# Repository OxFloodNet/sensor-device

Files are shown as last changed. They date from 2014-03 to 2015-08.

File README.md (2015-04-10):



#OxFloodNet Sensor Device

Sensor code (originally started at Sushack 2013 - http://www.sushack.co.uk/)
## Requirements
Base components:
 * Ciseco RFu-328 (SRF radio + ATMega328 module) with an ultrasonic sensor
 * Schematic and parts list shown in [PCB directory](https://github.com/OxFloodNet/sensor-device/tree/master/PCB)

## Output 
 * LLAP to transmit sensor readings
 * Sends messages in format: a<device ID><sensor ID><value><dash padding til 12 chars>
 * Example message: aR1U65------
 * Meaning: Device R1, Ultrasonic Sensor, Reading: 65cm to water surface.
 * Example message: aR1B5500----
 * Meaning: Device R1, Battery sensor, Reading: 5500mV (5.5v remaining in battery)
 
Typical sensor deployment
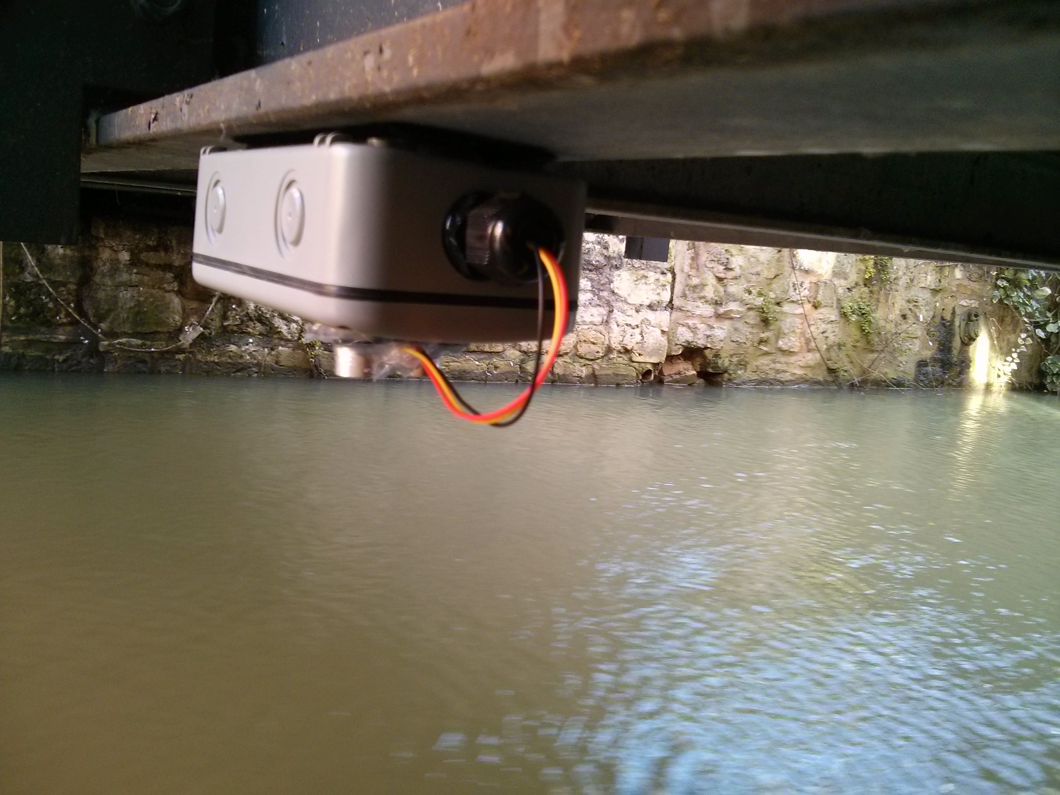
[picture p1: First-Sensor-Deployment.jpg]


Testing

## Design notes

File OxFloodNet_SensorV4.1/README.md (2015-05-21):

Oxford Flood Network Sensor Code
=================================

Version 4.1.0 - Codename: 

Features: 
* Compatible with Maxbotix ultrasonic sensor range using PWM interface
* Dallas DS18B20 Temperature sensor for speed of sound compensation and Unique ID
* Unique 8 hex character Node number
* Variable wake timer with jumpers
* Uses an Extended LLAP message format
* Variable polling during startup phase to test device is working
* STARTvvv message sent 5 times at start, vvv indicates firmware version
* Battery message sent every 10 readings
* Reset reedswitch.
* Test mode for verifying the hardware works correctly and for remote firmware loads.

Issues: 
* None identified yet

The Oxford Flood Network sensor V4.0 is based on the Arduino core and is written for the Ciseco RFu328 which uses the ATMega328 microcontroller. The code uses some direct register acesses, so may not be directly compatible with other non-ATMega328 based boards without modification. It uses the Ciseco/Wireless Things RFu328 which includes the Ciseco/Wireless Things SRF radio transceiver module. This is used to manage the very low-power sleep mode, with the SRF waking the 328 using an interrupt pin after the wakeup time is reached.

The code is intended to be generic, with the sleep interval set by jumpers on the PCB. These are directly connected to ATMega328 pins which are read at setup() and converted into parameters for "Wakeup Period". The board has no FTDI connector pins which means that the RFu328 must either be programmed using the Ciseco RFu dev board, Voyager adaptor or programmed over the air while in test mode.

Jumpers
-------

The 2 jumpers labeled 1 and 2 represent *Wakeup Period* and has four possible options:

<pre>
 1   2    Sleep Interval
[ ] [ ] - 15 Minutes (default)
[X] [X] - 10 Minutes
[ ] [X] - 5 Minutes
[X] [ ] - 1 Minute
</pre>

The Test jumper should only be used for testing the sensor. This will allow two way communication between a laptop and sensor to perform validation on the harware. Please see the Test Mode description below for full details.

ATMega328 I/O Pin usage
-----------------------

|I/O|Use|
|---|---|
|D0|Tx SRF Radio Module|
|D1|Rx SRF Radio Module|
|D2|Wakeup interrupt|
|D3|Ultrasonic Sensor input|
|D4|SRF Sleep selection|
|D5|Temperature sensor, One Wire bus|
|D6|Ultrasonic Sensor Enable - Low to enable|
|D7|Not used|
|D8|SRF Radio enable - High to enable|
|D9|Wakeup period|
|D10|Wakeup period|
|D11|Not Used|
|D12|Not Used|
|D13|Test Mode jumper. Low selects test mode on reset|
|A0-A5|Not used|

When programming sketches using the Arduino IDE, select board type "Arduino Uno".

Test Mode
=========

The test mode is available over the wireless connection so this must be working. The RFu-328 must also have the V4 sketch loaded. A Ciseco SRFStick is required to communicate with the sensor and needs to be configured to communicate with the sensor on an alternative PANID (Network ID). An alternative PANID is used so that communcations with the sensor under test do not interfere with other working sensors and similar equipment that is located nearby.

Setting up the SRFStick
-----------------------

You need to communicate with the SRFStick using suitable Serial terminal emulation software, for example TeraTerm on Windows. To setup the correc parameters you need to enter a number of AT commands. Enter AT mode by typing `+++`, you should then receive the OK response, if not repeat again. Once you see the OK response, enter the following AT commands, ensure each gives an OK response. They set the PANID to 2305, set the packet size to maximum, make the configuration active and exit AT mode.

<pre>
+++
OK
ATID2305
OK
ATPKF0
OK
ATAC
OK
ATDN
OK
</pre>

Once setup, placing a jumperlink on the `Test` pins and resetting the sensor by sliding a magnet along the edge near the battery should result in the menu being shown.

<pre>
Oxford Flood Network Sensor
===========================

Test Menu
=========
0 - Display Menu
1 - Display Address
2 - Read Temperature
3 - Read Raw Distance
4 - Read Distance
5 - Battery Voltage
6 - Read Polling Rate
Choice: [0 - 6]
</pre>

To select an option press the number 0-6. Options 1, 5 and 6 return immediately, options 2, 3 and 4 repeatedly update the results until a key is pressed. The interval between readings is 1/2 second. This allows changes in temperature and distance to be seen. Option 0 re-displays the menu.

### Sensor Address
This displays part of the unique ID from the temperature sensor. The family ID, CRC and extra 0's are removed to give an 8 hex character node address. A value of 00000000 indicates the address was not read from the sensor and needs ot be checked.

<pre>
Address: 04BB8405
</pre>

### Read Temperature
Displays the current temperature reading. Touching the sensor should increase the reading so show that it is working. A value of 85.00C indicates that the sensor is not functioning and may need to be checked or replaced.
<pre>
Read Temperature
Temperature: 17.50C
</pre>

### Read Raw Distance
Displays the raw distance or *Error* if the sensor is outside of its usable range.
<pre>
Read Raw Distance
Raw Distance: 160cm
</pre>

### Read Distance
Displays the temperature, raw distance and compensated distance or *Error* if the sensor is outside of its usable range.
<pre>
Read Distance
Temperature: 17.50C  Raw Distance: 160cm  Distance: 159cm
</pre>

### Battery Voltage
Display the battery voltage reading.
<pre>
Read Battery Voltage
Battery: 3.3943V
</pre>

### Read Polling rate
Displays the state of the two polling/sleep interval jumpers and the rate it represents.
<pre>
Read Polling Rate
Pin 1 No Jumper
Pin 2 No Jumper
Polling: 0
15 Minutes
</pre>

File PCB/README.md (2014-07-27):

This repository contains the EAGLE files and gerbers for creating an Oxfloodnet Sensor PCB v3.1. 

The sensor device has the following features:
* Arduino-compatible code wireless sensor node
* Wireless
  * Transmits using 433, 868 or 915* MHz  (*USA only)
  * LLAP Protocol
  * Up to 200m range
  * Chip, Wire Whip and External (u.FL) antenna options
* Power: 
  * Option for Long-life (1 x 3.6v Tadiran Lithium Cell) or Off-the Shelf (2 x 1.6v AA Batteries)
  * Battery voltage reading sent every 10th cycle
  * Extremely low power sleep mode (~30uA)
* Maxbotix ultrasonic ranger
  * Compatible with most Maxbotix sensors
  * Maxbotix MB7060 XL-MaxSonar-WR1 IP67 outdoor-rated sensor recommended due to humidity/condensation issues
  * Maxbotix MB1230 works but has condensation issues above streams
* DS18B20 temperature sensor 
  * to compensate for speed of sound in different conditions
  * Temperature data also a useful byproduct
  * Molex header connection to board for easy maintenance
* Jumpers/Headers
  * Control poll cycle (10s, 5, 10 or 15 minutes depending on jumpers)
  * FTDI connector for programming sketch to RFu-328 (not powered)
  * Molex temperature connector
  * Maxbotix 7-way header
  
See Arduino [device code](https://github.com/OxFloodNet/sensor-device/tree/master/OxFloodNet_Sensor) for more specific info about controlling these.

A schematic of the Oxfloodnet Sensor PCB v3.1  
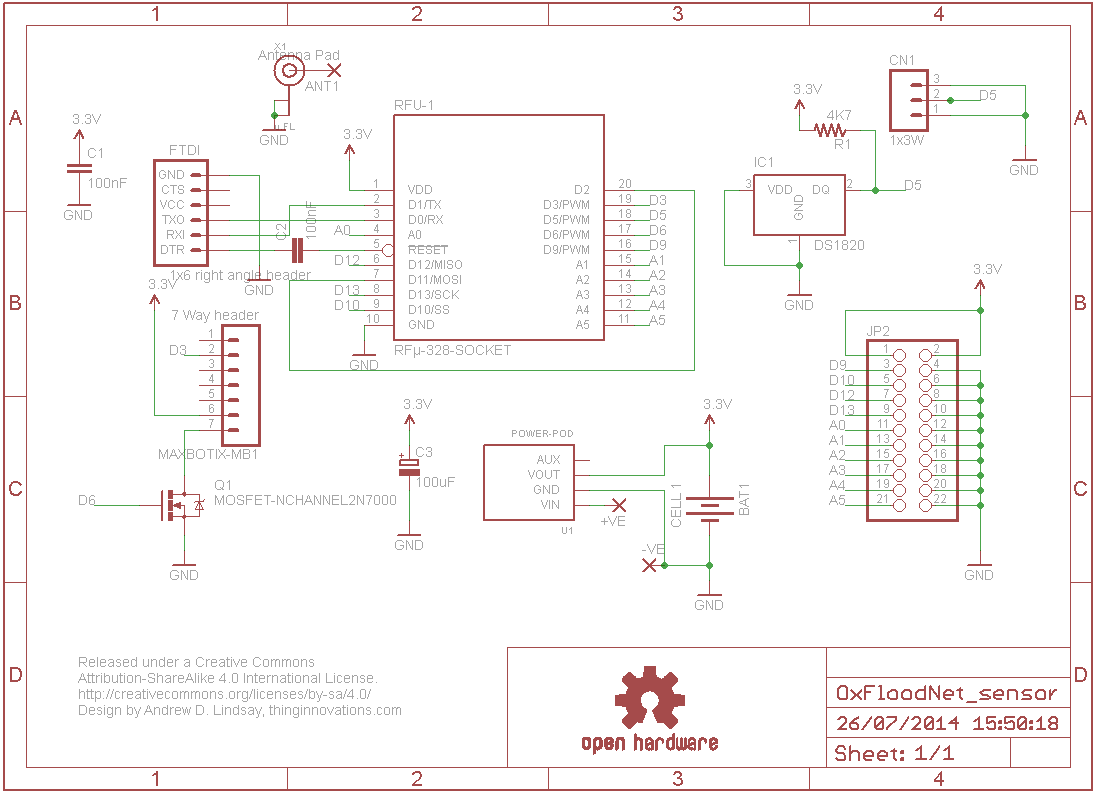
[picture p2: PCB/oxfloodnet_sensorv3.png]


The assembled v3.0 sensor can be seen in the pictures below along with aseembly instructions at [http://blog.thiseldo.co.uk/?p=1285](http://blog.thiseldo.co.uk/?p=1285). V3.1 assembly is similar, instructions will follow later.

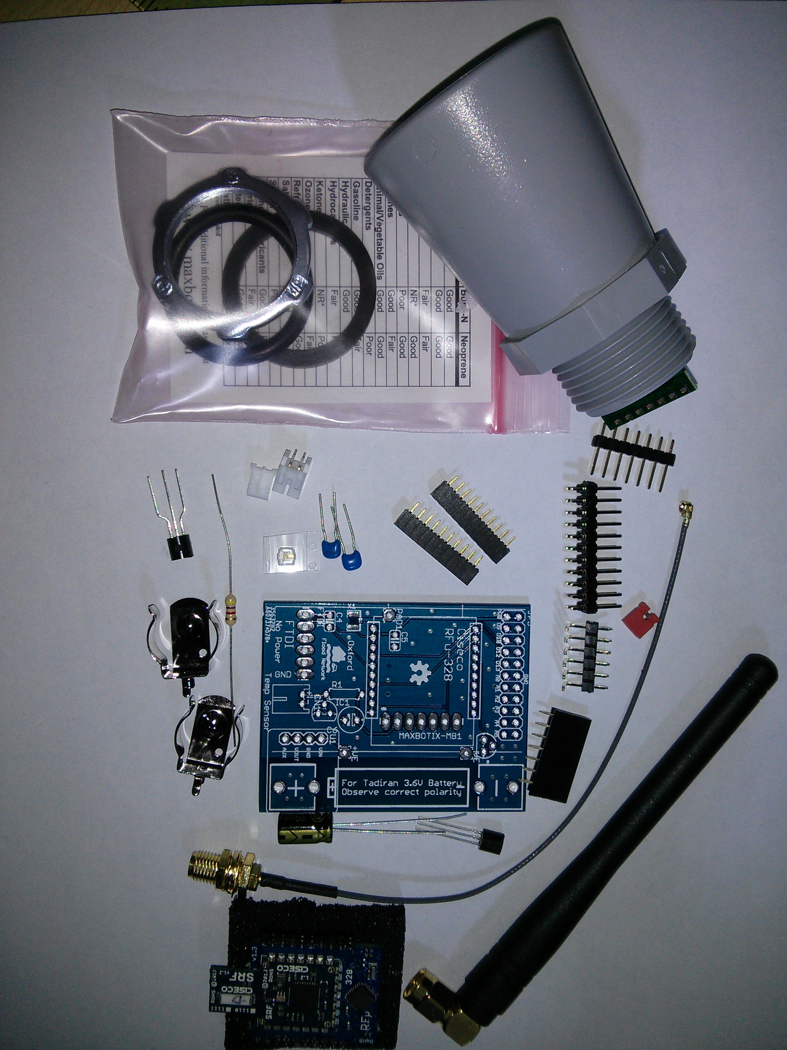
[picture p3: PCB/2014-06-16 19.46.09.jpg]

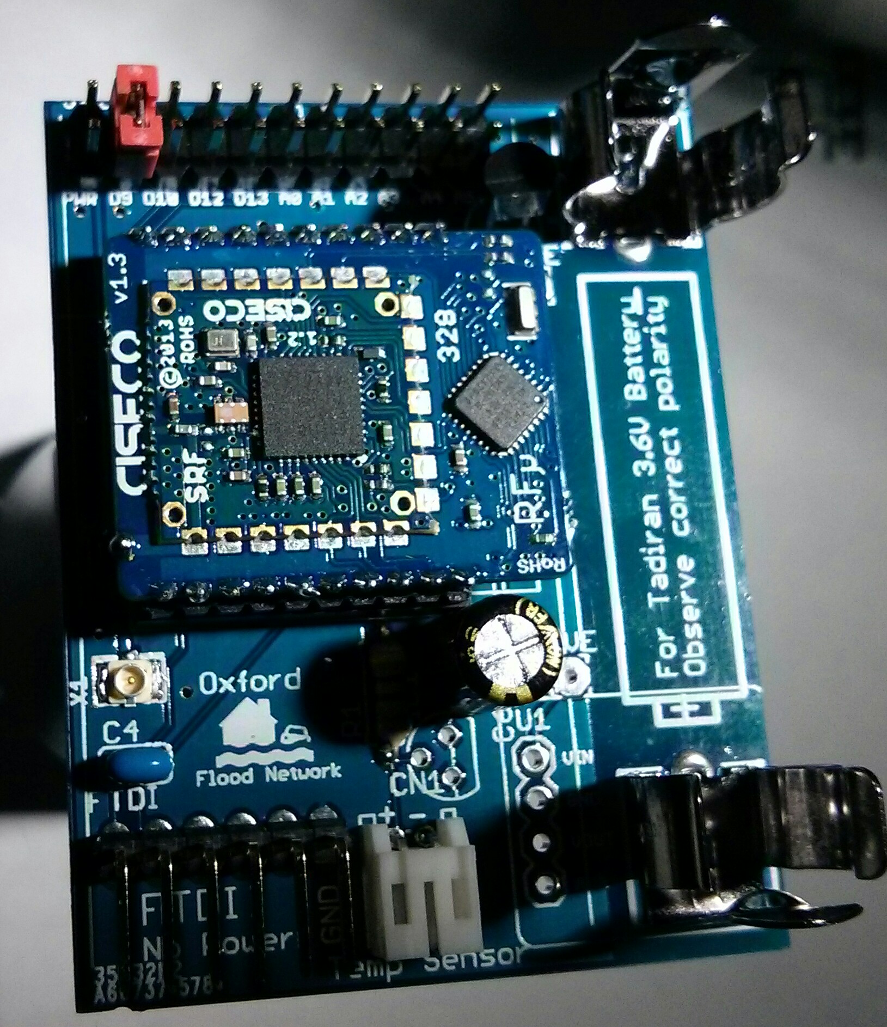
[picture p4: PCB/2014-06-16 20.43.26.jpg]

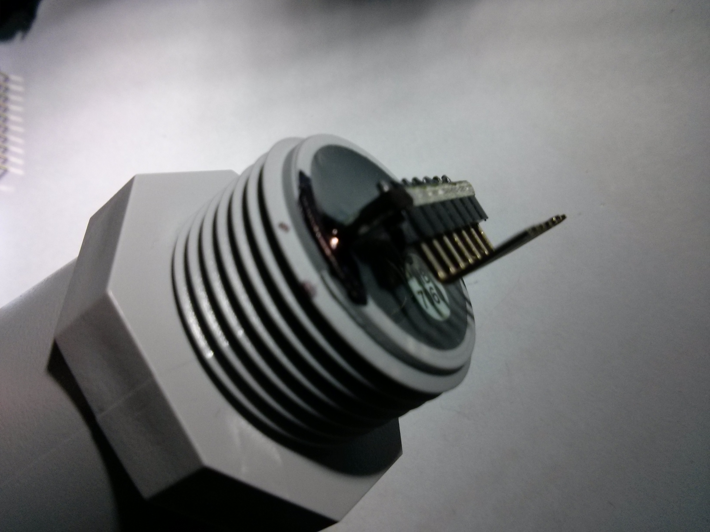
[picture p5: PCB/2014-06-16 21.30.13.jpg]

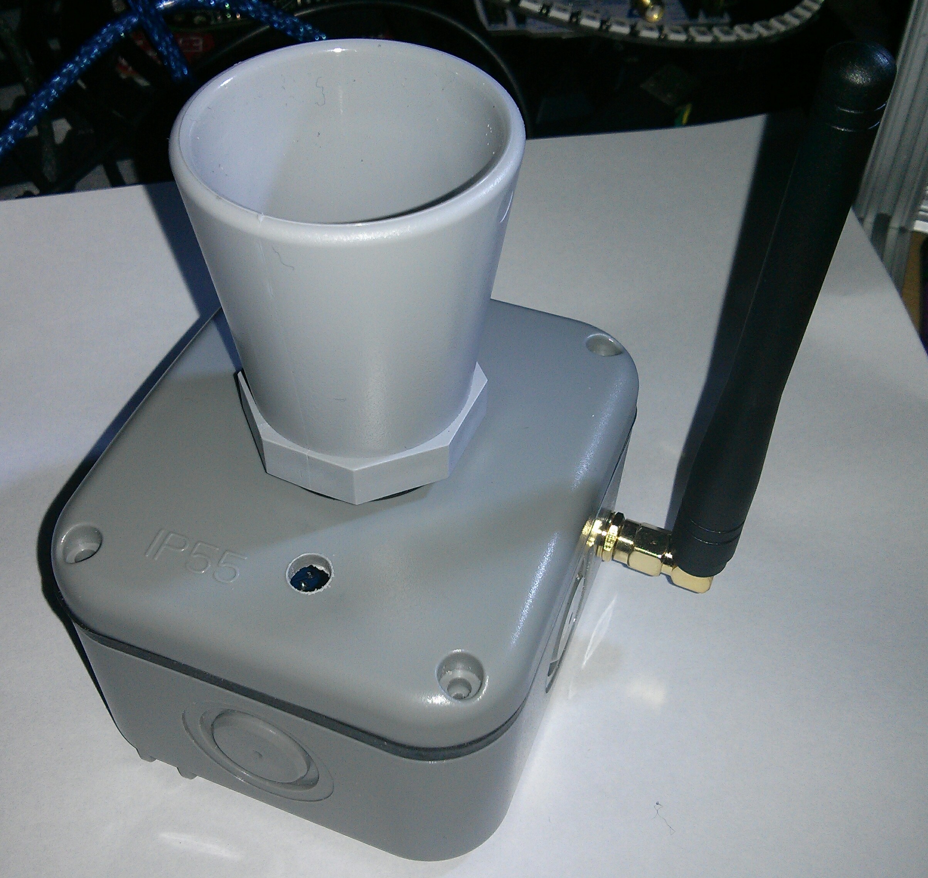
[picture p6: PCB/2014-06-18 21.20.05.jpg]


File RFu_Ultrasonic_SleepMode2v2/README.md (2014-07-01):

RFu_Ultrasonic_SleepMode2v2 - Deprecated
========================================

This code was deployed on the initial prototype sensor in Oxford in Feb 2014 and has now been replaced by https://github.com/OxFloodNet/sensor-device/tree/master/OxFloodNet_Sensor  

This version uses the RFu's sleep mode 2 to enable deep sleep low-power mode on the sensor device.  A small change is required to the Ciseco LLAP library to increase the sleep time to a longword rather than a word. The new version does not require this as it uses SRF's sleep mode instead.

The PDF schematic included in this repository was used for the hardware. There is a glaring error in this revision which leaches power constantly on pin A1 reading the battery level. This should be enabled and disabled using the NPN transistor instead. 

This schematic has been superceeded by the custom PCB.

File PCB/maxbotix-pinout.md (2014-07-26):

Maxbotix MaxSonar pinout:

PIN:

1. BW (RS232 control?)
2. Pulse Width Output [http://www.maxbotix.com/articles/033.htm](http://www.maxbotix.com/articles/033.htm)
3. Analog Voltage Output  [http://www.maxbotix.com/articles/032.htm](http://www.maxbotix.com/articles/032.htm)
4. Serial Interface RX
5. Serial Interface TX (Output)
6. V+
7. GND

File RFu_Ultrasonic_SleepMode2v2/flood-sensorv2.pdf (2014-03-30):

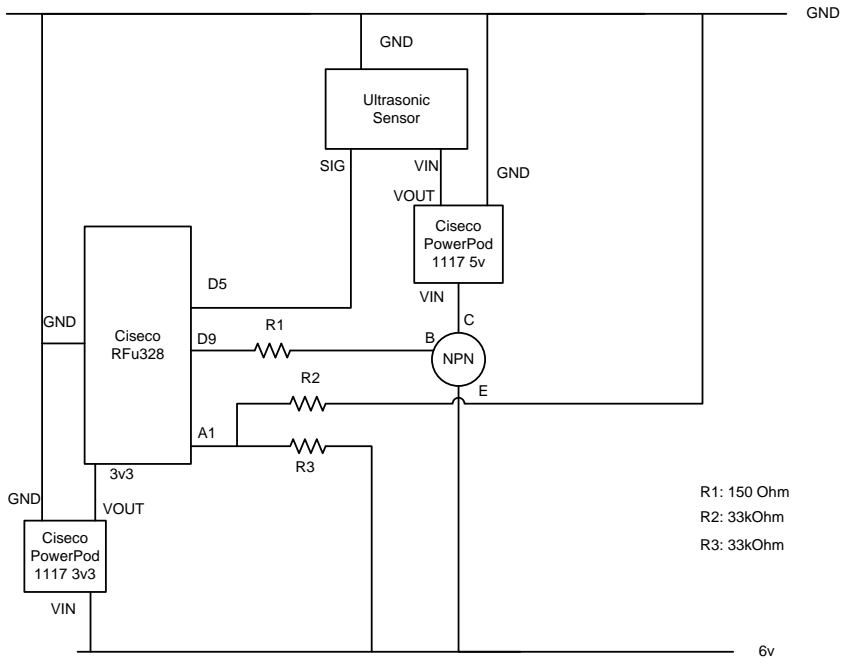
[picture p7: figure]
Ciseco RFu328; Ultrasonic Sensor; Ciseco PowerPod 1117 3v3; Ciseco PowerPod 1117 5v; NPN A1; VIN; VOUT GND; GND; SIG; VOUT; VIN R1; R1: 150 Ohm R2: 33kOhm R3: 33kOhm

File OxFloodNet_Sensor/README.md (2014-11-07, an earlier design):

Oxford Flood Network Sensor Code
=================================

Version 3.1.4 - Codename: Bulstake

Features: 
* Variable Node ID with jumpers
* Variable wake timer with jumpers
* Variable poling during startup phase to test device is working
* Dallas DS18B20 Temperature sensor for speed of sound compensation
* Compatible with Maxbotix ultrasonic sensor range using PWM interface
* STARTvvv message sent 5 times at start, vvv indicates firmware version
* Battery message sent every 10 readings

Issues: 
* >Max reading leads to no LLAP message being sent instead of error
* After programming unplug FTDI cable before trying normal operation (TX/RX get diverted)

OxFloodNet sensor V3.1 uses Arduino code. It's written for the Ciseco RFu328 which uses an ATMega328. The code uses some register settings, so is not directly compatible with other boards without modification. It relies on the Ciseco RFu328 which includes the Ciseco SRF radio transceiver. This is needed to manage the very low-power sleep modes, with the SRF waking the 328 up using an interrupt pin after a sleep timer completes.

The code is intended to be generic, with parameters being set by jumpers on the PCB. These are directly connected to ATMega328 pins which are read at setup() and converted into parameters for "Node ID" and "Wakeup Period". The board has no FTDI chip which means an FTDI programming cable is needed to update the code (must be removed again for board to operate properly)

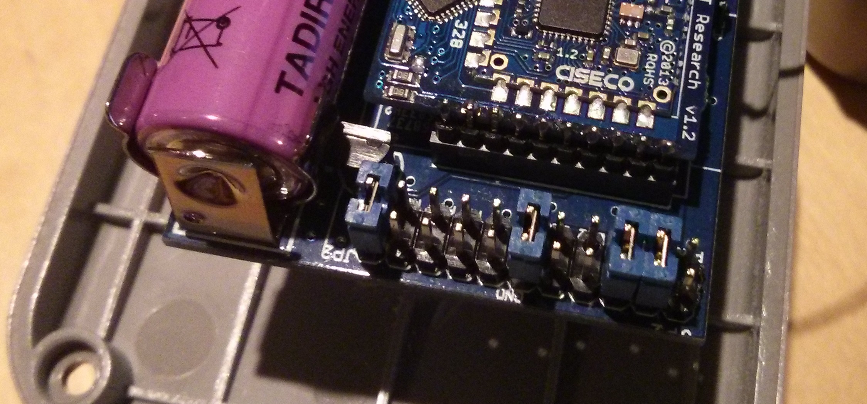
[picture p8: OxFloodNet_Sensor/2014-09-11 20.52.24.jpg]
OxFloodNet v3.1 PCB Jumper Layout Jumper Layout


In the image above, the jumpers should be read from left to right: 
<pre>
A5 ,A4 ,A3 ,A2   - Node ID high digit
A1 ,A0 ,D13,D12  - Node ID low digit
D10, D9          - Wakeup Period (backwards?)

The first eight represent the *Node ID* as two nibbles, four jumpers each:
<pre>

 High Hex Digit:
  8   4   2   1  (binary digit)
 A5  A4  A3  A2  (ATMega328 pin)
 
 Low Hex Digit: 
  8   4   2   1  (binary digit)
 A1  A0 D13 D12  (ATMega328 pin)
 
 Examples:
  Node ID 0x21 would be a jumper on A3 (2) and D12.   
  Jumper A4&A3&A0 would make 0x64. 
  Jumper D13&A5&A4 would make high digit: (8+4 = B) and low digit: (2) = 0xB2

</pre>

The 9th & 10th jumpers from the left represent *Wakeup Period* and has four possible values mapped
to a number of minutes to sleep for:
<pre>
D9  D10 Value
[ ] [ ] 0      - 15 Minutes (default)
[ ] [x] 1      - 10 Minutes
[x] [ ] 2      - 5 Minutes
[x] [x] 3      - 1 Minute
</pre>

The last jumper on the right is unused but is marked PWR. This for possible expanstion and additional sensors.

<pre>
Pin usage on ATMega328:

D3 - Sensor input
D5 - Temperature sensor, One Wire bus
D6 - Sensor Enable - Low to enable
D8 - SRF Radio enable - High to enable
D9 - Wakeup period 0
D10 - Wakeup period 1
D12 - First Node ID digit bit 0
D13 - First Node ID digit bit 1
A0 - First Node ID digit bit 2
A1 - First Node ID digit bit 3
A2 - Second Node ID digit bit 0
A3 - Second Node ID digit bit 1
A4 - Second Node ID digit bit 2
A5 - Second Node ID digit bit 3

AVR mapping
A0-5 - PC0 - PC5
D12, D13 - PB4, PB5
D9,D10 - PB1, PB2

Board type in Arduino IDE should be set to "Arduino Uno"

</pre>

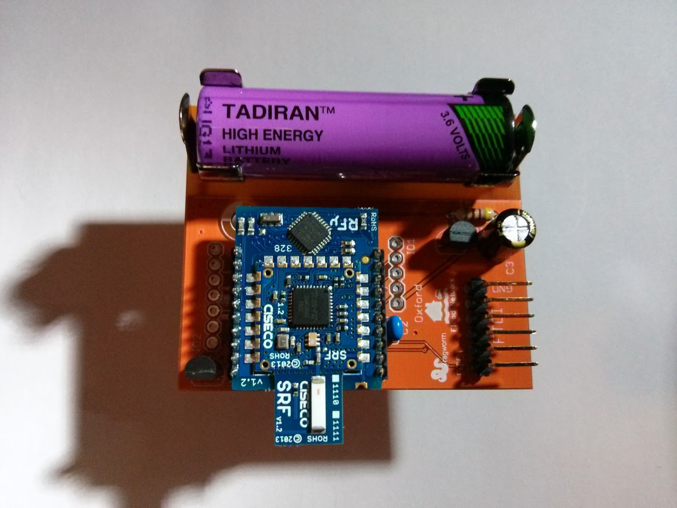
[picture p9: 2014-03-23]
PCB/2014-03-09 19.44.21.jpg

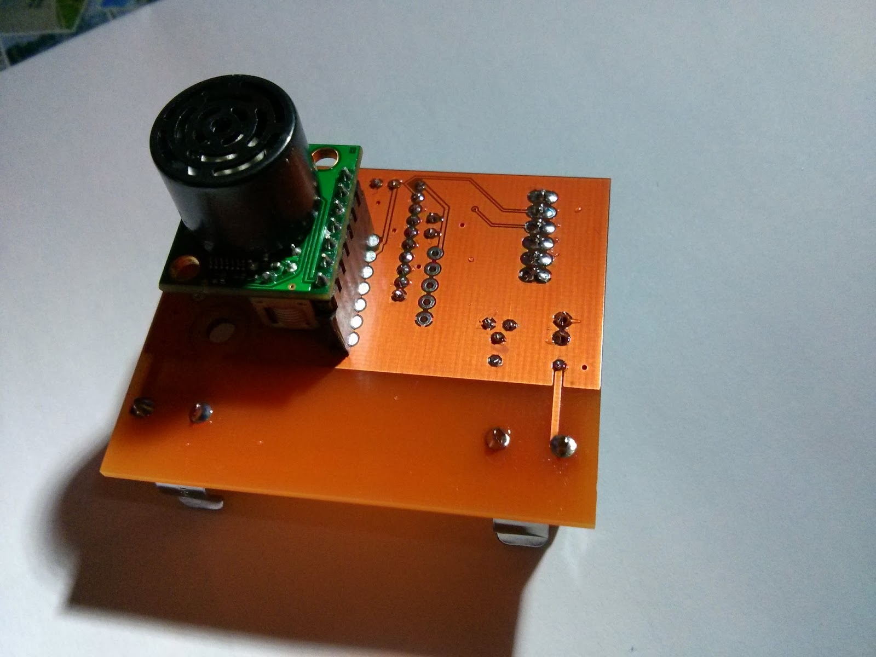
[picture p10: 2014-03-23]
PCB/2014-03-09 19.42.08.jpg

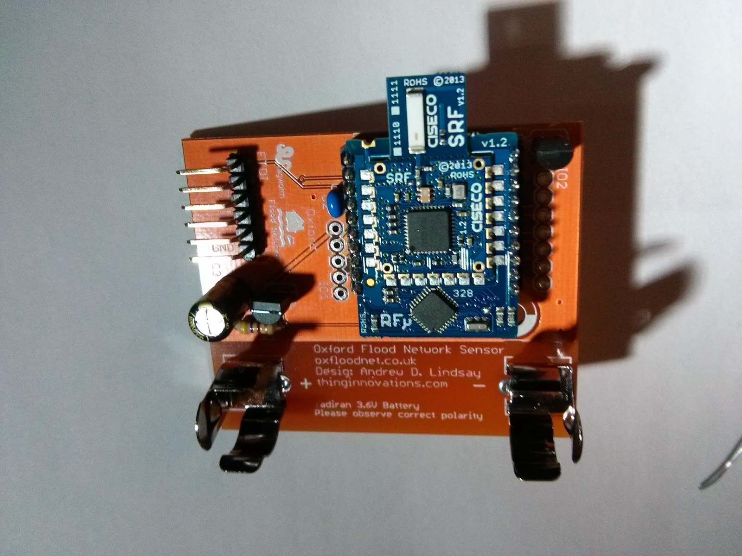
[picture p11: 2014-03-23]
PCB/2014-03-09 19.41.45.jpg

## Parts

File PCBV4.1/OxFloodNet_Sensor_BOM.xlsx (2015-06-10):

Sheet: BOM V4.1
Oxford Flood Network Sensor: Bill of materials
Version: | V4.1 | Farnell parts are suggestions, other sources may be cheaper.
Part Number | Value | Quantity | Supplier | Supplier Part No. | Unit Cost | Total Cost
PCBOFN4.1 | PCB, V4.1 | 1 | Thing Innovations | PCBOFN4.1 | 3 | 3
C1 | 100nF Ceramic multilayer | 1 | Farnell | 2309020 | 0.04 | 0.04
C2 | 100uF Electrolytic 10V, D6.3xH5 Pitch2.5 | 1 | Farnell | 8766878 | 0.16 | 0.16
JP1 | 1x2W Header pins | 1 | Farnell | 1022263 (36 way, cut down) | 0.66 | 0.66
JP2 | 2x2W Pin Header pins | 1 | Farnell | use above |  | 0
IC1 | DS18B20 - 1-Wire Digital Thermometer | 1 | Farnell | 1187948 | 4.3 | 4.3
HDR1 | 1x7W Header - Long Pins (8W stackable header) | 1 | Bitsbox | CN312 | 0.4 | 0.4 | 8 Way, but need to remove 1 pin
MAXBOTIX-MB1 | 1x7W Right Angle Header pins | 1 | Farnell | 1097958 (36 way, cut down) | 1.29 | 1.29 | But min 28 way lengths more cheaply and cut down
Q1 | 2N7000 Mosfet-N Channel | 1 | Farnell | 9845178 | 0.11 | 0.11
R1 | 4K7, 1/4W Resistor | 1 | Farnell | 2329534 | 0.02 | 0.02
SKT1,2 | 10w 2mm socket | 2 | Farnell | 1109732 | 0.84 | 1.68
S1 | Reed switch STANDEXMEDER MK6-5-B | 1 | Farnell | 1079479 | 1.14 | 1.14
U$1 | Ciseco RFµ-328 | 1 | Ciseco | RFµ-328 | 13.99 | 13.99
SENSOR1 | Maxbotix MB7060 XL-MaxSonar-WR1, Standard edition | 1 | Technobots online | Maxbotix MB7060 XL-MaxSonar-WR1 | 76.16 | 76.16
SENSOR2 | WR Mounting Hardware, Maxbotix MB7950 | 1 | Technobots online | Maxbotix MB7950 | 1.88 | 1.88
CASE1 | RP1025 (65x60x40mm) with Machining OFN-CASE-001 | 1 | Evatron | RP1025 | 2.55 | 2.55
CASE2 | Enclosure mounting feet | 0.5 | Evatron | MF0041 (4 feet, 2 needed) | 1.06 | 0.53
BATT1 | AA Snap in Battery clip | 2 | Farnell | 908733 - Pack of 5 | 0.22 | 0.44
CELL1 | 3.6V Tadiran SL-760 AA | 1 | Battery Station | SL-760 AA |  | 0
ANT1 | Antenna wire, 90mm (Gauge???) | 1 | Farnell |  |  | 0 | Already have some of this from last time
ANT2 | Antenna tube, RC tube cut to 100mm, white. | 1 | ?? |  |  | 0
 |  |  |  |  |  | 108.35

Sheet: Suppliers
Suppliers
Farnell | uk.farnell.com
Ciseco | shop.ciseco.co.uk
Thing Innovations | thinginnovations.com | Andrew Lindsay/Oxford Flood Network
Technobots Online | www.technobotsonline.com
Battery Station | www.batterystation.co.uk
Bitsbox | www.bitsbox.co.uk

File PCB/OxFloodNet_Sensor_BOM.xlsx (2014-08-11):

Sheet: BOM V3.1
Oxford Flood Network Sensor: Bill of materials
Version: | V3.1 | Farnell parts are suggestions, other sources may be cheaper.
 | External Antenna | Yes
 | Power Source | 2xAA
Part Number | Value | Quantity | Supplier | Supplier Part No.
PCBOFN3.1 | PCB, V3.1 | 1 | Thing Innovations | PCBOFN3.1
C1, C2 | 100nF Ceramic multilayer | 2 | Farnell | 2309020
C3 | 100uF Electrolytic 16V, D6.3xH11 Pitch2.5 | 1 | Farnell | 1144614
CN1 | 1x3W Right angle Header pins | 1 | Farnell | 2356177
CN2 | 1x3W Header | 1 | Farnell | 1098033
FTDI | 1x6W Right angle Header pins | 1 | Farnell | 2356180
JP2 | 2x11W Pin Header pins | 1 | Farnell | 2356134 (2x12W, cut down)
IC1 | DS18B20 - 1-Wire Digital Thermometer | 1 | Farnell | 1187948
MAXBOTIX-MB1 | 1x7W Header | 1 | Farnell | 1098037
 | 1x7W Right Angle Header pins | 1 | Farnell | 2356182
Q1 | 2N7000 Mosfet-N Channel | 1 | Farnell | 9845178
R1 | 4K7, 1/4W Resistor | 1 | Farnell | 2329534
SKT1,2 | 10w 2mm socket | 2 | Farnell | 1109732
U$1 | RFµ-328 | 1 | Ciseco | RFµ-328
SENSOR1 | Maxbotix MB7060 XL-MaxSonar-WR1, Standard edition | 1 | Technobots online | Maxbotix MB7060 XL-MaxSonar-WR1
 | WR Mounting Hardware, Maxbotix MB7950 | 1 | Technobots online | Maxbotix MB7950
 | 20cm hookup wire, 0.2mm2, blue | 1 |  | Cost for guidance only | Only availble in min 1m lengths or reels from Farnell.
 | 20cm hookup wire, 0.2mm2, brown | 2 |  | Cost for guidance only | Only availble in min 1m lengths or reels from Farnell.
 | 2mm Heatshrink tubing, 5cm | 1 |  | Cost for guidance only | Only availble in min 1m lengths or reels from Farnell.
 | 4mm Heatshrink tubing, 2cm | 1 |  | Cost for guidance only | Only availble in min 1m lengths or reels from Farnell.
 | IP55 Enclosure Grey 85 x 75 x 65mm. | 1 | Screwfix | Stock No: 33991
External Antenna - Additional Parts
X1 | u.FL Antenna Connector | 1 | Ciseco | u.FL Antenna Connector
 | u.FL Antenna to SMA pigtail | 1 | Ciseco | u.FL Antenna to SMA pigtail
PAD1 | 1w 2mm socket & Pin | 1 | Farnell | 1109732 and 2289780 10w cut down | Use 2 x 1109732 and 1 x 2289780 per 10 units
ANT | External Antenna | 1 | SK Pang | ANT-900MR
3.6V Single AA Cell power option
BAT1 | AA Snap in Battery clip | 2 | Farnell | 908733 - Pack of 5
 | 3.6V Tadiran SL-760 AA | 1 | Battery Station | SL-760 AA
Dual Cell AA power option
 | 2xAA battery holder with leads | 1 | Farnell | 1702631
 | 1x4W Header | 1 | Farnell | 1098034
U1 | PowerPOD NCP1402 3V3 | 1 | Ciseco | PowerPOD NCP1402 3V3

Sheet: Suppliers
Suppliers
Farnell | uk.farnell.com
Ciseco | shop.ciseco.co.uk
SK Pang | www.skpang.co.uk
Thing Innovations | thinginnovations.com | Andrew Lindsay/Oxford Flood Network
Technobots Online | www.technobotsonline.com
Battery Station | www.batterystation.co.uk

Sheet: Sheet1
Yes | 3.6V Tadiran
No | 2xAA

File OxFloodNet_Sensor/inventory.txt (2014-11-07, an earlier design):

22 - External Antenna v3.1.2 - 5 seconds - Hogacre bracket mount
42 - External Antenna v3.1.2 - 20 seconds
84 - External Antenna v3.1.2 - 20 seconds

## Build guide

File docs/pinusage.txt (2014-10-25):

Oxford flood network sensor pin usage

D3 - Sensor input
D5 - Temperature sensor, One Wire bus
D6 - Sensor Enable - Low to enable
D8 - SRF Radio enable - ??? to enable
D9 - Wakeup period 0
D10 - Wakeup period 1
D12 - First Node ID digit bit 0
D13 - First Node ID digit bit 1

A0 - First Node ID digit bit 2
A1 - First Node ID digit bit 3
A2 - Second Node ID digit bit 0
A3 - Second Node ID digit bit 1
A4 - Second Node ID digit bit 2
A5 - Second Node ID digit bit 3

Wakeup Period Jumpers

15 mins - None fitted
10 mins - 0 fitted
5 mins - 1 fitted

1 min - 0 and 1 fitted
or
20 Sec - 0 and 1 fitted - Ideal for testing instead of 1 min.

AVR mapping.
A0-5 - PC0 - PC5
D12, D13 - PB4, PB5
D9,D10 - PB1, PB2

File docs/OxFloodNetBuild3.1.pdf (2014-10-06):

## Oxford Flood Network Sensor Build Guide

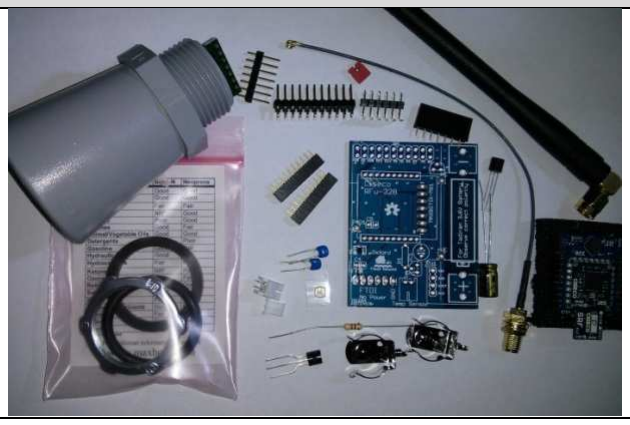
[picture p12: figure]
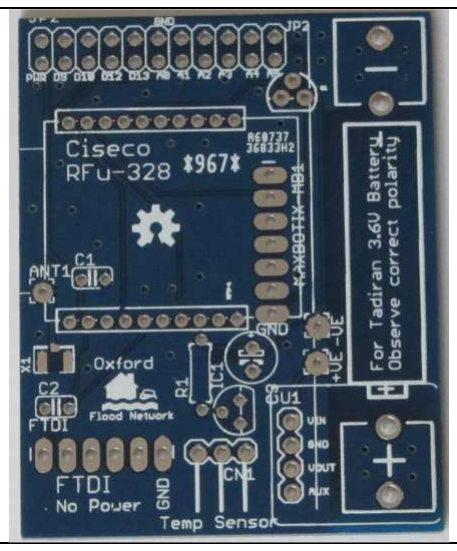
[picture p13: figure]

Andrew Lindsay, 06/10/2014 | 1

Sensor build instructions v3.1

Main PCB

The build includes optional steps for the external antenna and the wire whip antenna options. These should be followed depending on which option you are building.

Step | Details | Photo
1 Start by examining the kit of parts and | identify each part. The kit of parts without the case, connecting wire, battery and heat shrink tube are shown.
2 Tools needed: | • Soldering iron • Side Cutters • Wire strippers • Tweezers • Long nose pliers • Helping-hands or PCB holder to hold the PCB and components during soldering • Blu-tack • Heat gun for heat shrink tubing (Or disposable lighter). • Desoldering tool or braid (in case of mistakes!)
3 The first part of the sensor build is to | examine the printed circuit board (PCB) and familiarize yourself with the location of the components. Not all the pads are used as the board has a number of power and antenna options that are detailed in this guide.

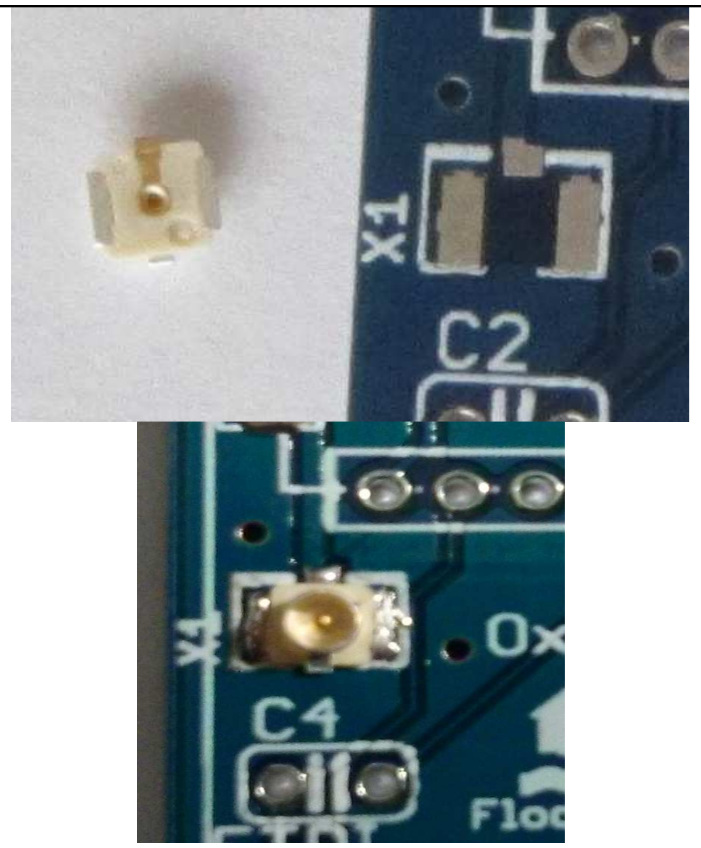
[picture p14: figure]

4 NOTE: External Antenna option only. If | using wire whip antenna then please ignore this step. Start by soldering the lowest components first, this is the u.FL connector that is only needed if you are using the external antenna. It is important to get this round the correct way. Looking underneath the connector, you can see only one outer connector goes to the centre pin. This is gold in colour and is the side that must be soldered towards the centre pad at the top of the picture. Beware, these can be tricky to solder. Using a small blob of blu-tack (or similar) can help.

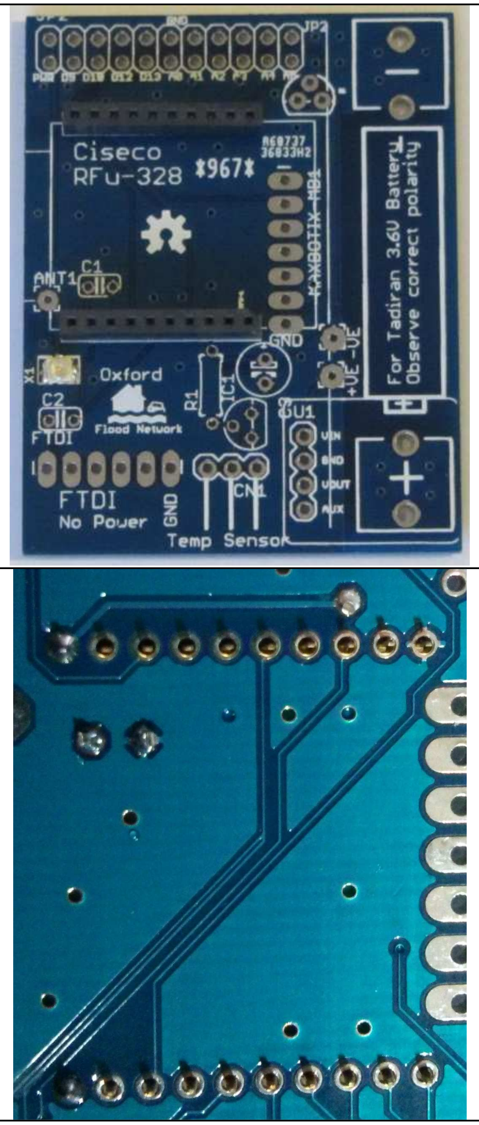
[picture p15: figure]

5 The pair of 10 way header sockets | should be soldered next. Start by soldering one end only then turn the board over to check that the connector is straight and level. If it’s not straight then it can be moved from side to side to position it then just touch the soldering iron on the joint to re-align it.
6 Solder the other end then check again. | Once you’re happy its straight then solder the remaining pins. Repeat for the other socket.

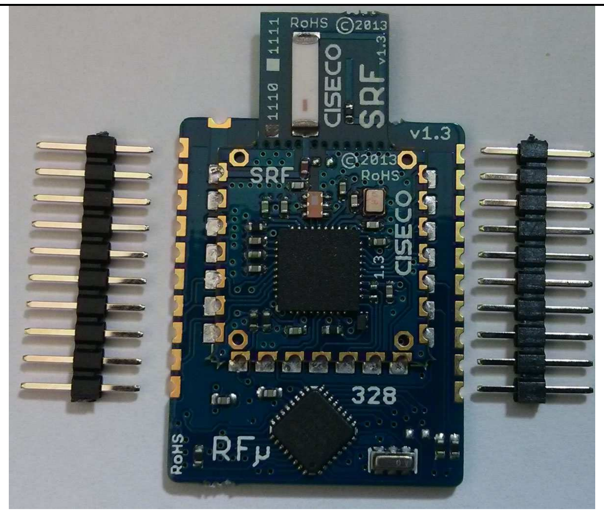
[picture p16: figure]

7 The Ciseco RFµ-328 module needs the | header pins soldering. These are in the package with the module. The easiest way to do with is to plug the two rows of pins into the socket with the longer pin into the socket and the shorter pin sticking up. Place the RFu module onto the pins so that they are in the semi-circular cutouts. Once you are happy with the fit, solder the pins carefully. If you are not fitting the external antenna then remove the module by carefully pulling upwards.

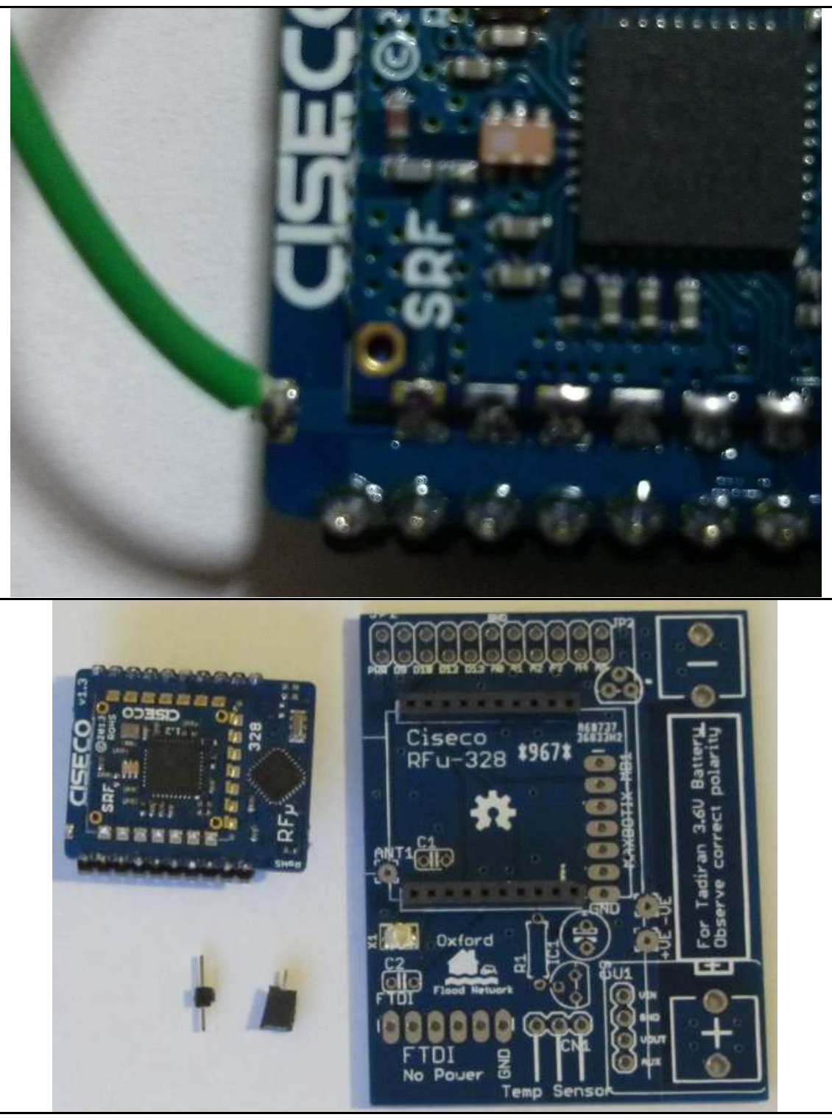
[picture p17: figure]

8 NOTE: Wire Whip antenna option only. | Strip 2mm of the sheath from one end of an 85mm piece of wire. Solder this to the pad at the top of the RFµ-328. The antenna can then be trimmed to 82mm above the PCB. The wire whip can then be curled loosely in the case when the PCB is mounted on the sensor.
9 NOTE: External Antenna option only. | The Ciseco RFµ-328 module shown here has the inbuilt antenna snapped off. The module requires an additional pin to link the antenna to the u.FL socket. The kit provides a small pin and header that may need to be trimmed to a single pin and header.

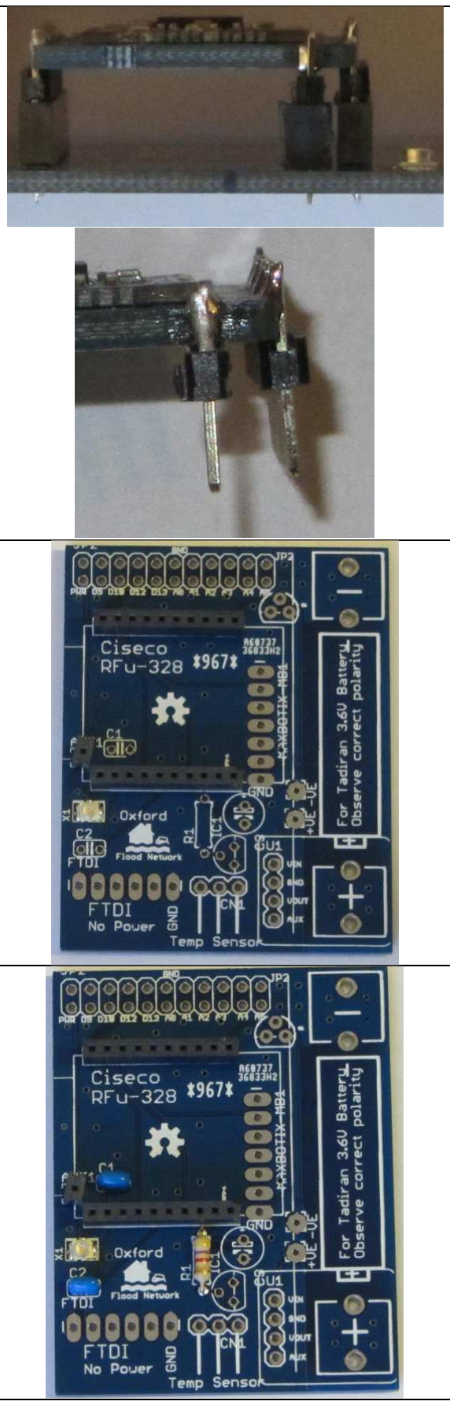
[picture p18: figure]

10 NOTE: External Antenna option only. | Plug the header pin and socket together, insert the socket into the PCB and line the pin up with the semi-circular cutout on the RFu module. Solder the pin end first then turn over to solder the header socket. The RFµ module can now be removed carefully by pulling gently upwards.
11 NOTE: External Antenna option only. | The additional header socket should look like this.
12 Carefully bend the legs of the 4K7 | resistor close to the body so that they fit through the holes for R1. The two small capacitors, usually coloured blue or yellow are put into positions C1 and C2, the legs can be spread outwards to hold them while turning the board over. The resistor and capacitors should be soldered and the surplus leads trimmed closed to the board.

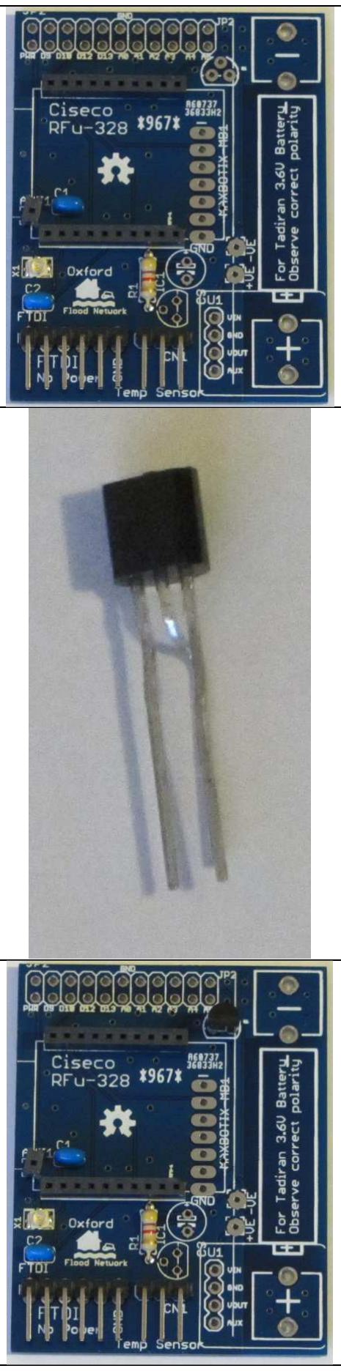
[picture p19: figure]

13 The 6-way and 3-way right angle | header pins are next. The black plastic strip should be next to the PCB. These should be soldered on one pin first. Check they are straight and square to the board before soldering the remaining pins. The 6-way header pins are for the FTDI programming cable, the 3-way header pins are for the temperature sensor.
14 The 2N7000 Field Effect Transistor | (FET) should be identified by the markings on its flat face. Do not mix this up with the temperature sensor DS18B20 which is in an identical TO-92 3 pin package. The centre leg should be bent backwards about 5mm down from the body, then a further 2mm down it should be bent downwards. The front is the flat face, the rear the curved side. This puts the centre leg behind the two outer legs forming a triangle that should match the holes towards the top of the PCB.
15 The prepared FET should be pushed | carefully into the holes as shown. The legs can be spread slightly from underneath to stop it falling out when turning the PCB over. Solder one leg, check the FET is straight, carefully re-position if it is not then solder the remaining legs. Trim the excess leads.

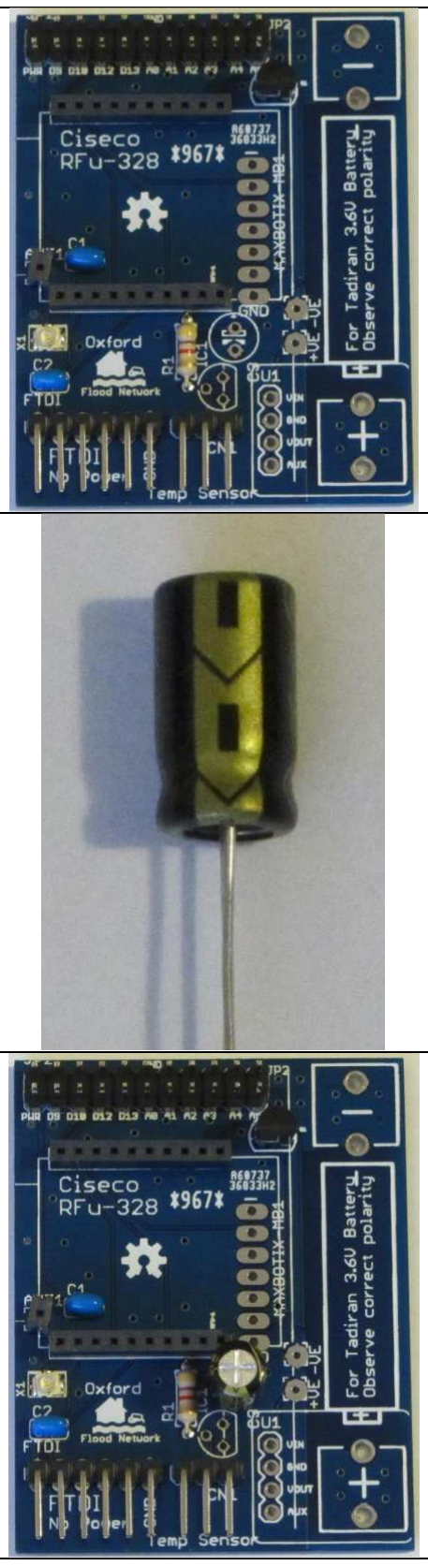
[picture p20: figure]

16 The double row of 11 pins should be | soldered next. Again, follow the procedure of soldering a corner pin, checking position then soldering all the remaining pins.
17 The electrolytic capacitor must be fitted | correctly. The capacitor has the – lead identified, but the PCB has a + marked on it. The – lead goes into the lower hole, the + is the top hole closes to the RFµ-328 module socket. The silkscreen on the PCB isn’t clear enough.
18 Solder the electrolytic capacitor, | observing the correct polarity. Trim the leads once done.

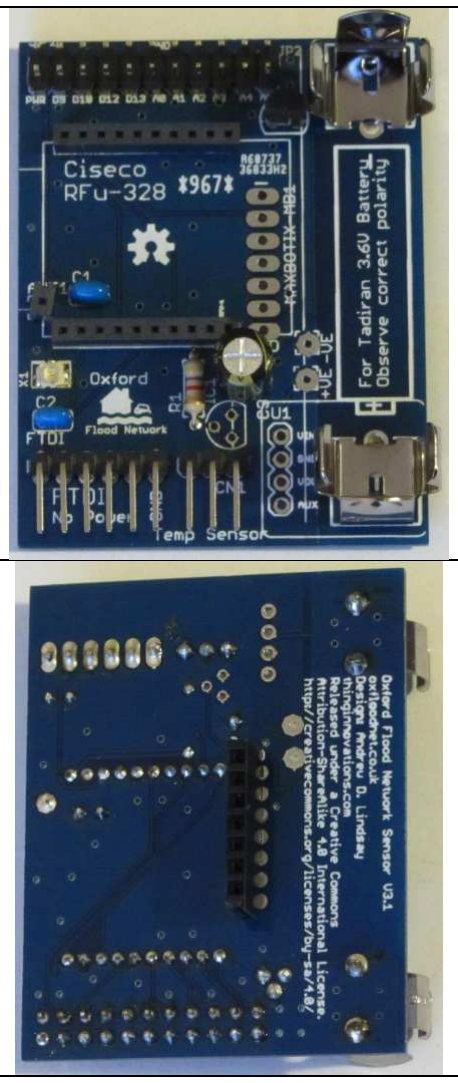
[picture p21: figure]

19 Push the two battery clips into the holes | on the PCB. Make sure they are firmly down. Turn the PCB over and solder each of the 2 legs on each clip. These will require quite a lot of heat and solder but be careful not to overdo it and burn the PCB. Warning: The battery clips will still be hot after soldering.
20 The ultrasonic transducer connector is | fitted from the underside of the PCB. Follow the usual procedure of soldering one end. The soldering for this connector is done on the top of the board.
21 The board is now complete, but before | installing the RFµ-328 module and battery, visually check all solder joints for shorts, solder splashes and dry joints. [TESTS]

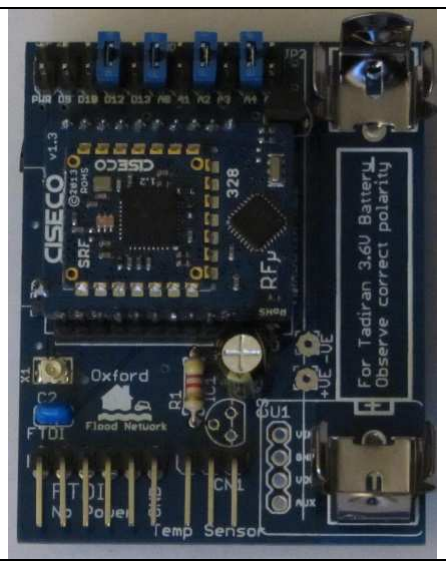
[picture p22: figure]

22 The completed board with RFµ-328 | module fitted. Take care to align the pins correctly before firmly pushing it into the socket.

Ultrasonic Sensor

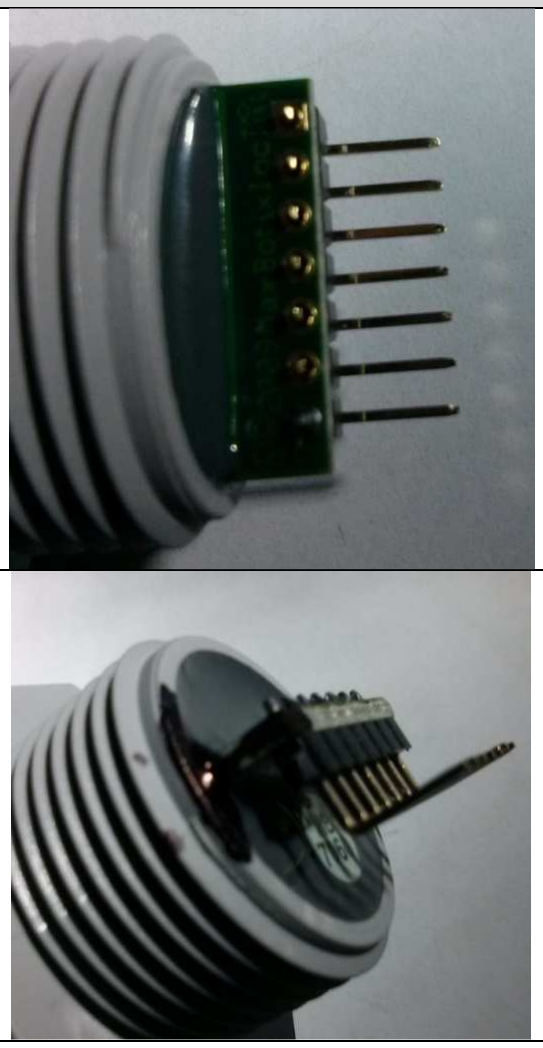
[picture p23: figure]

Step | Details | Photo
U1 | The 7-way right angle header pins need to be soldered onto the Ultrasonic sensor. The black plastic strip should be next to the PCB. The pins should go in through the side with the model number sticker as this is the largest area for the pins. One point to note is that once the pins have been fitted it may be difficult to identify the correct way round for the sensor to fit onto the main PCB. Examine the connector and identify the end hole labeled GND. Using a black marker pen, make a mark on the grey plastic at the GND end as shown in the photo below.
U2 | Follow the same procedure as before by soldering one end, checking position then soldering the remaining pins. The sensor is now ready to fit into the case.

Temperature Sensor

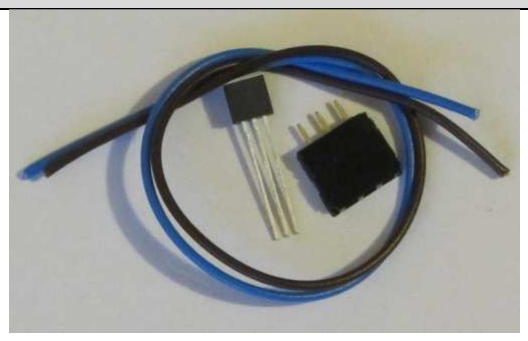
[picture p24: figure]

Step | Details | Photo
T1 | The DS18B20 temperature sensor, not to be confused with the similar looking 2N7000 FET needs to be wired to the three way header so that it can attach to the main PCB. The sensor has 3 legs but we are using it in a parasitic power mode so only need two connections. The heat shrink tubing is also required here.

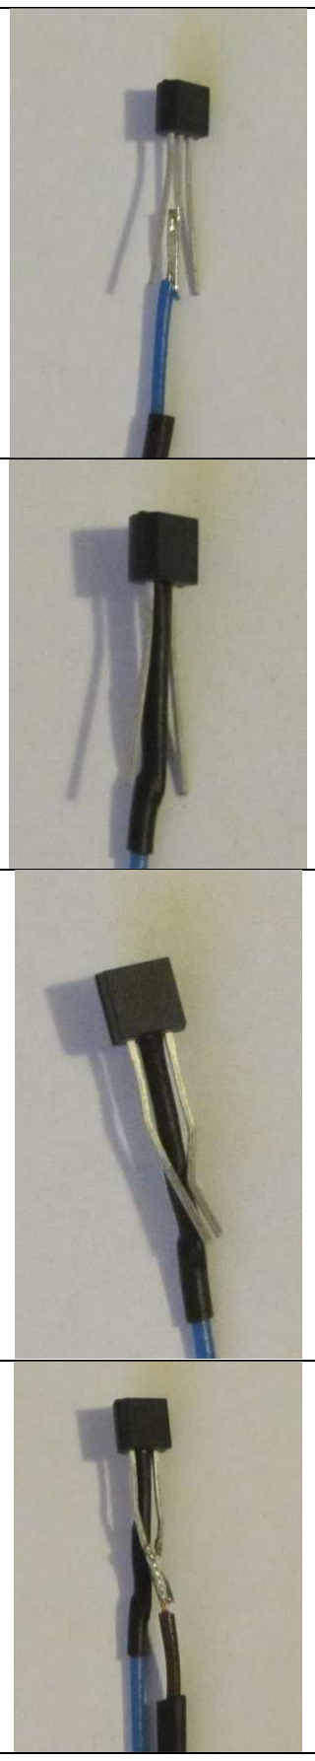
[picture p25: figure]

T2 | Separate the outer legs away from the centre leg to make soldering easier. Strip about 4mm of the insulation from the blue wire then twist and tin the exposed conductor. Solder this to the centre leg.
T3 | Slide a 15mm piece of narrow heat shrink tubing over this pin right up to the top. Using a heat gun, heat the tubing to shrink it.
T4 | The outer legs should be bent so that they meet in the middle, being careful not to bend too close to the black body of the temperature sensor.
T5 | The piece of brown wire can be stripped and tinned then soldered to the two outer legs as shown. A 15mm piece of narrow heat shrink can be pushed up as far as it can go then shrunk using a heat gun.

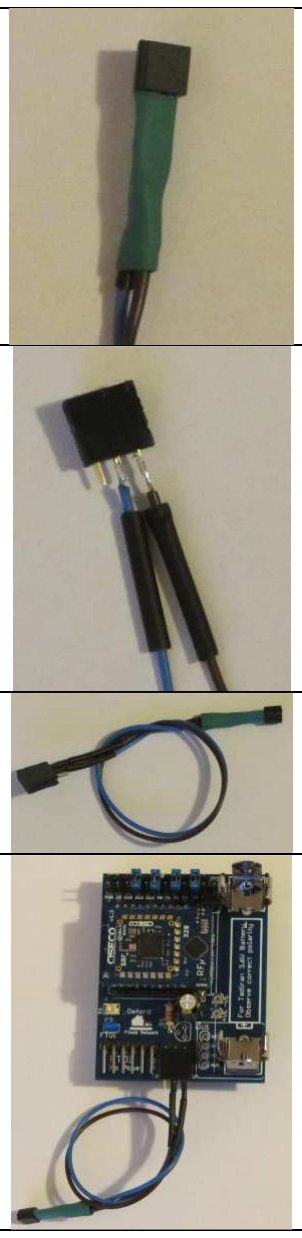
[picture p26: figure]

T6 | A larger piece of heat shrink tubing should be used to completely cover both the leads.
T7 | The other ends of the blue and brown wires should be stripped and tinned. Slide 10 – 15mm pieces of heat shrink tubing onto the wires then solder the blue wire to the centre of the 3-way header pins. Solder the brown to one of the outer pins. Slide the heat shrink tubing up and heat to shrink.
T8 | The finished temperature sensor should look like this.
T9 | The temperature sensor is plugged onto the 3-way header pins. The connector and temperature sensor has been designed so that it does not matter which way it is plugged in, it will work.

Case
The case may arrive pre-machined with the kit; if this is the case then instructions can be ignored.
Step | Details | Photo
C1 | The following build instructions refer to the IP55 rated junction box from Screwfix, as listed in the BoM. This is a 2-part case with rubber gasket between the base and the lid. Note when drilling and cutting plastic, the bit or saw will get hot causing the plastic to melt. Adjust the speed to help reduce overheating.

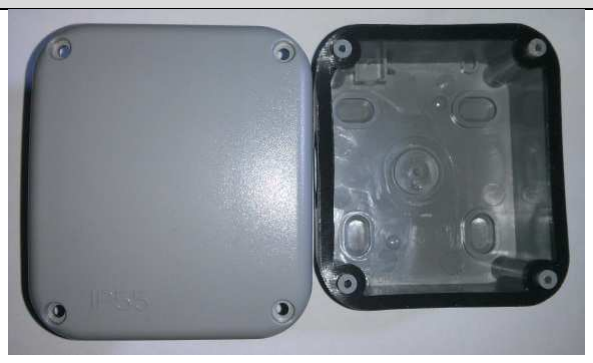
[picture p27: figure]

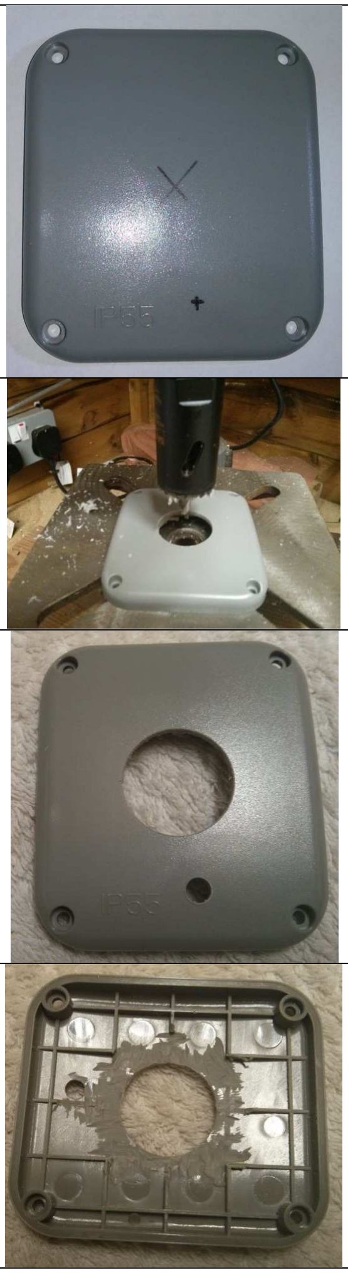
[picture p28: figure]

C2 | The hole for the ultrasonic sensor needs to be in the centre of the lid. Mark the centre by drawing lines from each diagonally opposite screw hole. A further mark is needed for the temperature sensor. This is approx. 15mm from the bottom edge and 10mm to the right of the centre line.
C3 | Using a 26mm (27mm maximum) hole saw mounted in a pillar drill is the easiest method to make the hole. If this is not available then the hole can be made using a smaller drill bit to produce a ring of holes, this is then cut out and the hole filed to the correct size.
C4 | The temperature sensor hole should be made with a 5mm drill bit.
C5 | The case used has a series of ribs inside the lid. These need to be removed around the hole so that the rubber O-ring can sit flush and the nut can be tightened. This can be done with a cutting disk in a rotary tool.

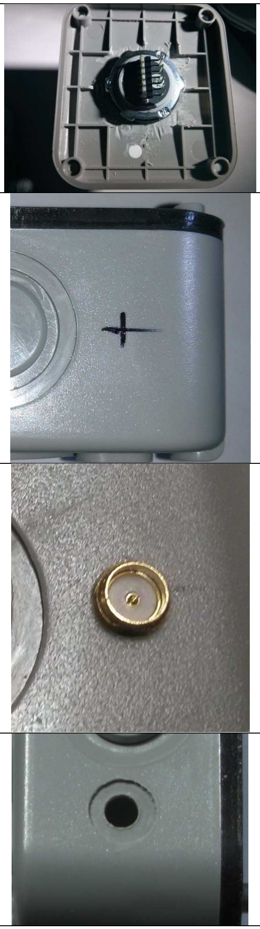
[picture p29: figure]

C6 | Fit the ultrasonic sensor. This should have the flat rubber washer on the outside and the rubber O-ring on the inside. Carefully tighten the large nut using either the proper spanner (!?) or a pair of long nose pliers, being careful not to damage the header pins.
C7 | NOTE: External Antenna option only. If the external antenna is to be used then a 6.5mm (or 6mm then run a file through hole to enlarge it).
C8 | NOTE: External Antenna option only. The SMA pig-tail should push through and be bolted in place. However, the plastic of the case may be too thick to let the antenna screw home fully.
C9 | NOTE: External Antenna option only. It is possible to produce a recess to thin the case where the connector is to be fitter. This can be done using a 12mm Forstner bit. These are special tools for cutting flat bottomed holes. In this case it was used to thin case. Ideally this should be done before the 6.5mm hole is made otherwise the tool may not centre correctly causing the tool to slip across the case.

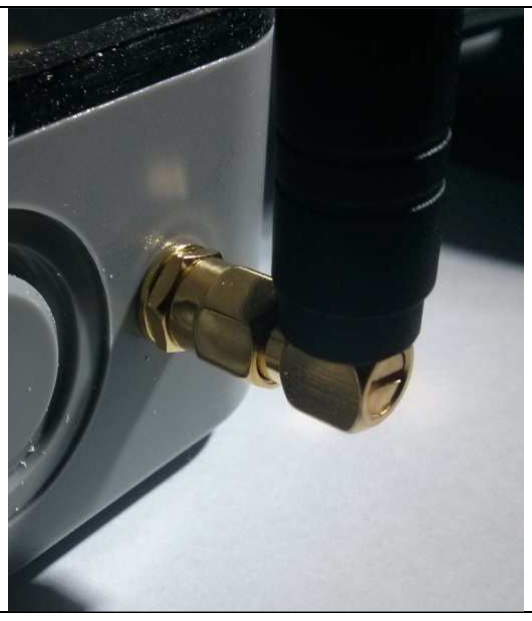
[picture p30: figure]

C10 | NOTE: External Antenna option only.
| The SMA connector should be tightened up using a pair of 8mm spanners so that the connector doesn’t turn when the antenna is fitted.
| For weather protection, the connector can be sealed with silicone sealant once the antenna has been fitted.

The completed sensor:

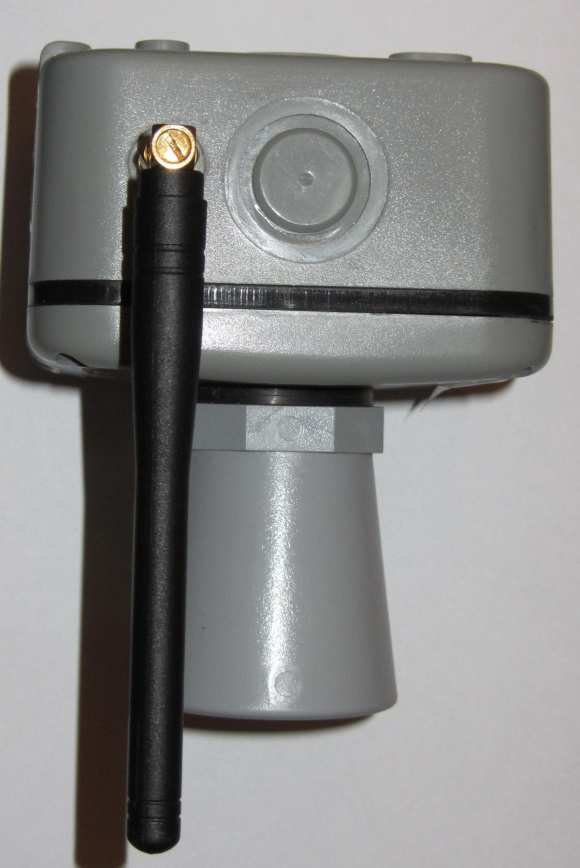
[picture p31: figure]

All that remains is to decide how to attach the sensor to your chosen location. We have tried:

- Industrial strength Velcro
- Old hard disc magnets inside the case
- Bracket screwed onto case

You should also consider a safety line to attach the sensor to the bridge in case it gets knocked from its mounting. This is especially important if the magnetic option is used. Suitable safety line would be steel cable, such as bicycle brake cable inner, small gauge chain or cable.

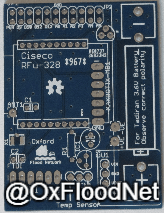
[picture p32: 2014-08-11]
build-guide.gif

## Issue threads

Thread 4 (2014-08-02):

How do we manage Node IDs?

crouchingbadger, 2014-08-02:
The node IDs for LLAP are supposed to be entirely numeric. The LLAP messages we're sending use letters and digits (eg. R1, L1). Should we change to the addressing scheme of LLAP?

If we do then we need to avoid two gateways receiving the same message. Can we use a unique hardware ID from either the SRF or the Dallas DS18S20? (We could stuff the unique ID into LLAP messages occasionally so the gateway can map the 2 digit ID to the globally unique one.)

crouchingbadger, 2015-04-10:
Decided to extend LLAP protocol, using DS18B20 sensor ID as the device's ID. This means the ID is longer than before, but more unique.
Andrew has prefxed all new LLAP messages with a 'b' character to differentiate them.

Closed 2015-04-10.

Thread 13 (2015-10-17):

Readings <22cm are being transmitted

crouchingbadger, 2015-10-17:
Since we've installed more v4.1 sensors the number of spikes (peaks caused by low readings) has massively increased. Readings <22cm are below the minimum distance and should not be transmitted. Instead, consider an error message.

Debugging would also be useful to see
1) if all the reads on a particular wakeup period are < 22cm
2) the potential causes of this. Why does it fail to read?

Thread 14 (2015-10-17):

Temperature Readings of 85C are being transmitted

crouchingbadger, 2015-10-17:
When the temperature sensor fails to read a temperature it returns 85. This is being accepted as a valid reading rather than being rejected. As a result the temperature compensation code causes Distance readings to fluctuate.

Consider
1) debugging and looking for the cause of a failed read.
2) writing validation code where readings of 85 degrees need to either be rejected or transmit an error.

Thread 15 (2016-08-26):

re: Wirelessthings

flcgit, 2016-08-26:
Hi,

1000 apologies, not really an issue, but I couldn't see any private email addreses.

I am aware you use  WirelessThings/Ciseco radios, like myself and it would appear they are closing.

OpenMicros site & WirelessThings site are down, although the latter was up not so long ago.

Ref:
http://www.insidermedia.com/insider/midlands/365agile-confirms-nottingham-closure

Rgds,
Chris.

crouchingbadger, 2016-08-26:
Thanks for letting us know. This has been circulating for a while.

We've moved to using LoRaWAN modules from Multitech which are a good near compatible replacement for hardware, but the code is now in mbed. 2nd Generation devices are based on this combination instead. They're Things Network compatible which will help with coverage.

Closed 2016-08-26.

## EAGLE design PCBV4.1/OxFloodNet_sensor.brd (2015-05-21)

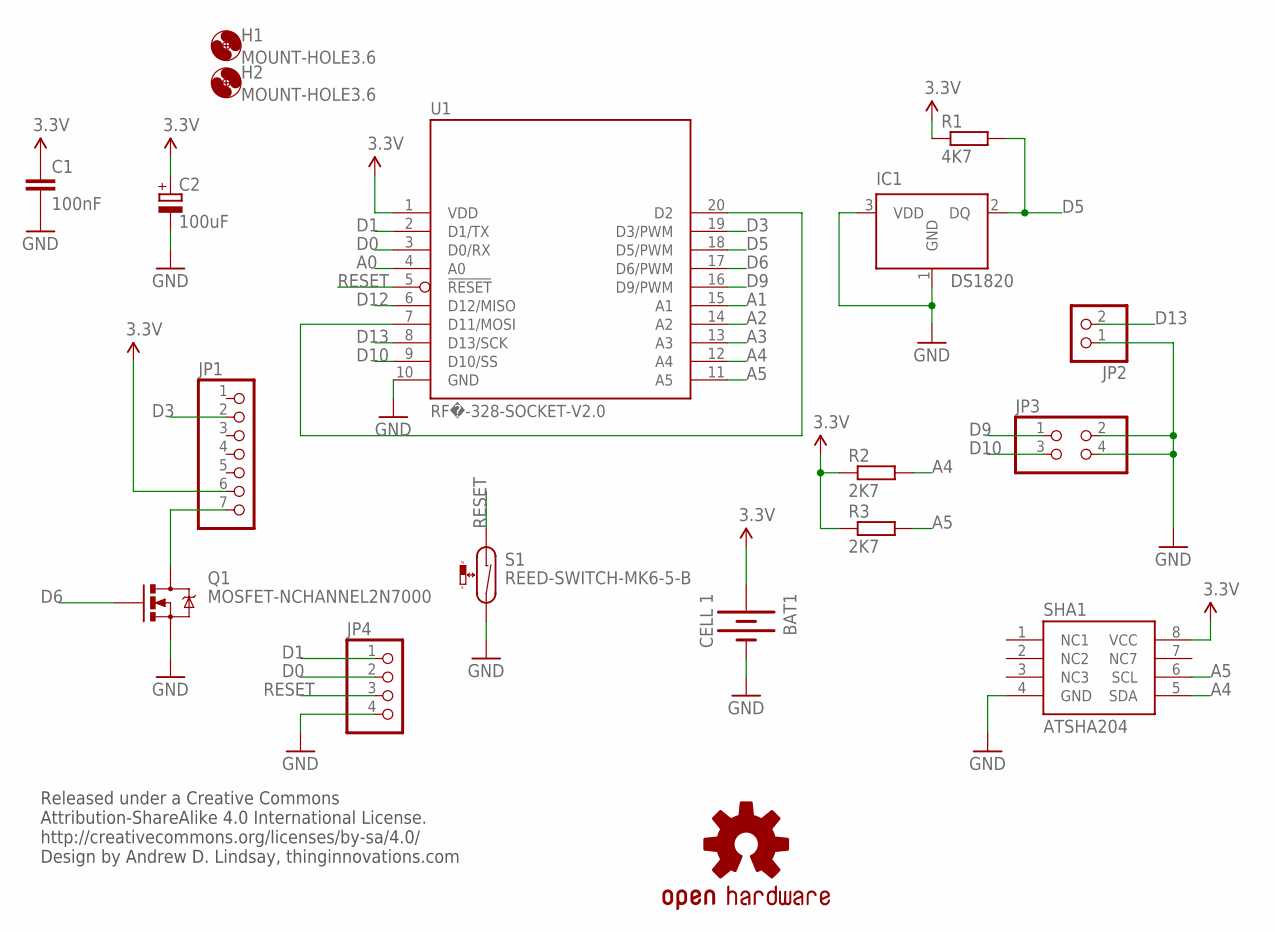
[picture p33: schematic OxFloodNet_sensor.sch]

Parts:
BAT1: CELL 1; BATTERY-AA
C1: 100nF; C025-024X044
C2: 100uF; E2,5-6E
H1, H2: MOUNT-HOLE3.6; 3,6
IC1: DS1820; TO-92
JP1: 1X07
JP2: 1X02
JP3: 2X02
JP4: PINHD-1X4; 1X04
LOGO1: OSHW-LOGOM; OSHW-LOGO-M
Q1: MOSFET-NCHANNEL2N7000; TO-92
R1: 4K7; 0207/7
R2, R3: 2K7; 0207/7
S1: REED-SWITCH-MK6-5-B; MK6-5
SHA1: ATSHA204; SOIC8
U1: RF�-328-SOCKET-V2.0; RF�-SOCKET-V2.0

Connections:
3.3V: BAT1.PWR@1 (+), C1.1, C2.+, JP1.6, R1.1, R2.1, R3.1, SHA1.8 (VCC), U1.1 (VDD)
A0: U1.4 (A0)
A1: U1.15 (A1)
A2: U1.14 (A2)
A3: U1.13 (A3)
A4: R2.2, SHA1.5 (SDA), U1.12 (A4)
A5: R3.2, SHA1.6 (SCL), U1.11 (A5)
D0: JP4.2, U1.3 (D0/RX)
D1: JP4.1, U1.2 (D1/TX)
D3: JP1.2, U1.19 (D3/PWM)
D5: IC1.2 (DQ), R1.2, U1.18 (D5/PWM)
D6: Q1.2 (G), U1.17 (D6/PWM)
D9: JP3.1, U1.16 (D9/PWM)
D10: JP3.3, U1.9 (D10/SS)
D12: U1.6 (D12/MISO)
D13: JP2.2, U1.8 (D13/SCK)
GND: BAT1.GND@1 (-), C1.2, C2.-, IC1.1 (GND), IC1.3 (VDD), JP2.1, JP3.2, JP3.4, JP4.4, Q1.1 (S), S1.2, SHA1.4 (GND), U1.10 (GND)
unnamed: U1.7 (D11/MOSI), U1.20 (D2)
unnamed: JP1.7, Q1.3 (D)
RESET: JP4.3, S1.1, U1.5 (!RESET)

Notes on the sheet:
Released under a Creative Commons Attribution-ShareAlike 4.0 International License. http://creativecommons.org/licenses/by-sa/4.0/ Design by Andrew D. Lindsay, thinginnovations.com

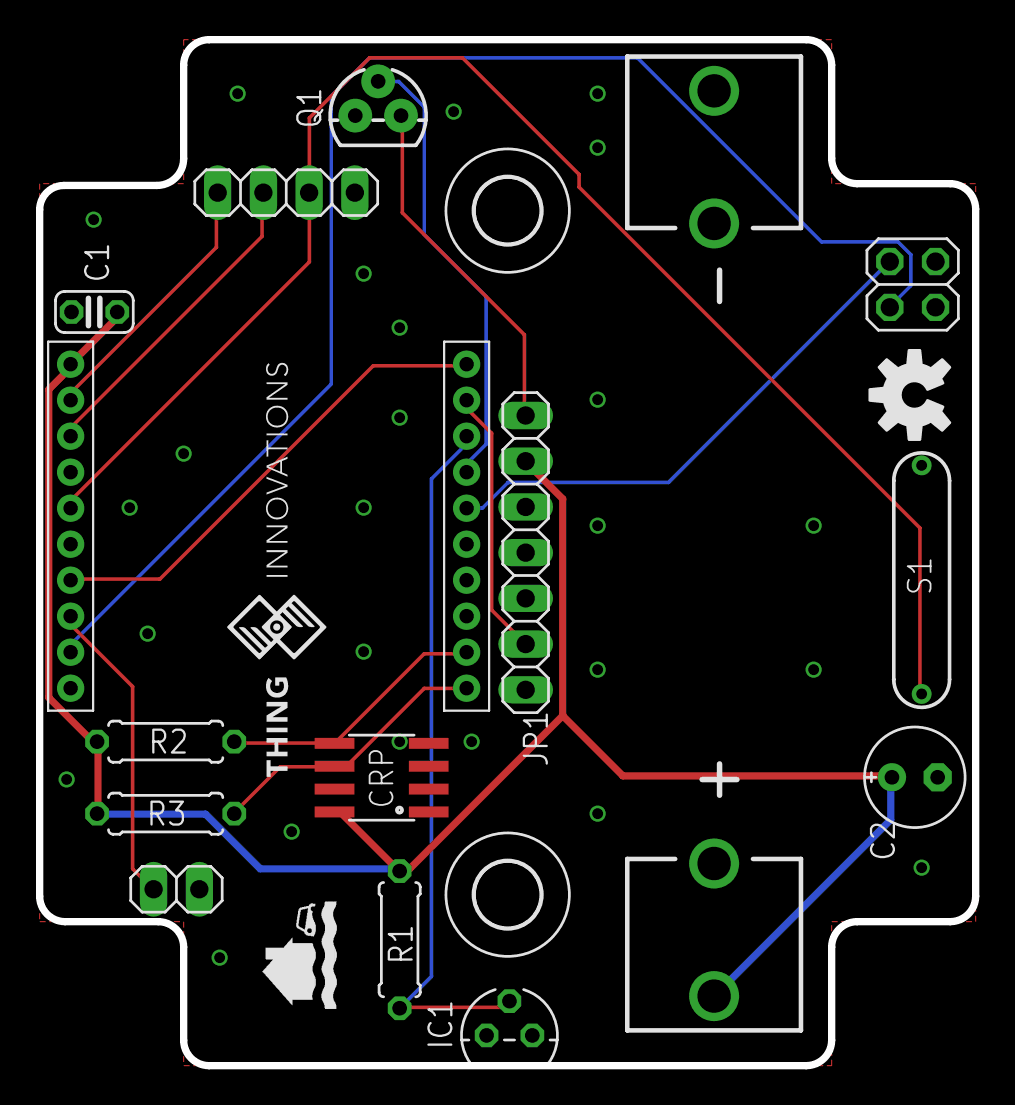
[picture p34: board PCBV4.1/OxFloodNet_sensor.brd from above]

Board: 2 copper layers, 52.0 x 57.0 mm, 19 parts (0 on the bottom side), 15 nets.

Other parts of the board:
U$1: THING_INNOVATIONS_SMALL

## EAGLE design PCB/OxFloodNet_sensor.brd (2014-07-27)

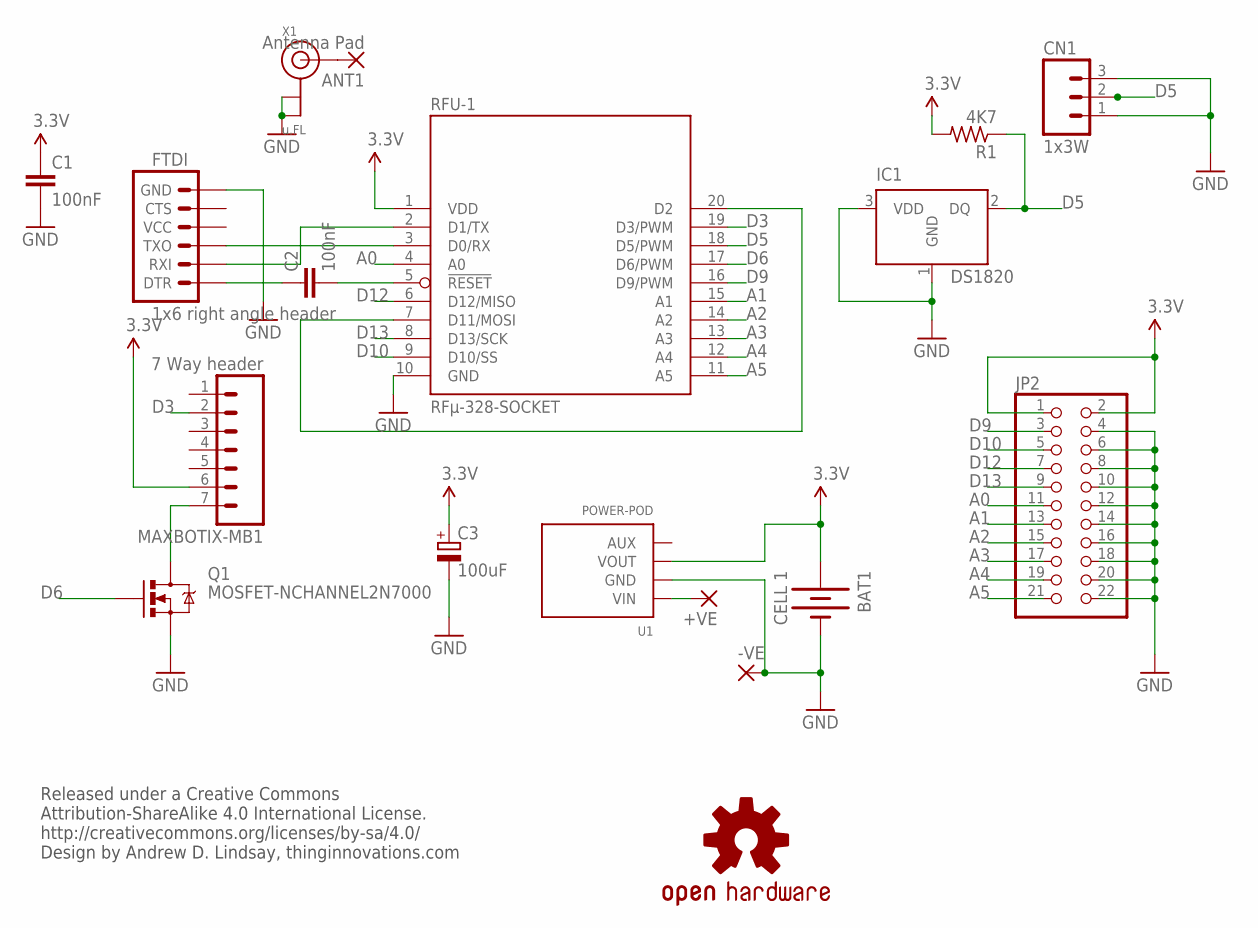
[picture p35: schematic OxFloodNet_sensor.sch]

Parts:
+VE: 2,54/0,8
-VE: 2,54/0,8
ANT1: Antenna Pad; 2,54/0,8
BAT1: CELL 1; BATTERY-AA
C1, C2: 100nF; C025-024X044
C3: 100uF; E2,5-6E
CN1: 1x3W; 1X03
FTDI: 1x6 right angle header; 1X06_LONGPADS
IC1: DS1820; TO-92
JP2: PINHD-2X11; 2X11
LOGO1: OSHW-LOGOM; OSHW-LOGO-M
MAXBOTIX-MB1: 7 Way header; 1X07_LONGPADS
Q1: MOSFET-NCHANNEL2N7000; TO-92
R1: 4K7; 0207/7
RFU-1: RFµ-328-SOCKET
U1: POWER-POD; POWER-POD-LANDING
X1: u.FL; U.FL

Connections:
3.3V: BAT1.PWR@1 (+), C1.1, C3.+, JP2.1, JP2.2, MAXBOTIX-MB1.6, R1.2, RFU-1.1 (VDD), U1.3 (VOUT)
A0: JP2.11, RFU-1.4 (A0)
A1: JP2.13, RFU-1.15 (A1)
A2: JP2.15, RFU-1.14 (A2)
A3: JP2.17, RFU-1.13 (A3)
A4: JP2.19, RFU-1.12 (A4)
A5: JP2.21, RFU-1.11 (A5)
D3: MAXBOTIX-MB1.2, RFU-1.19 (D3/PWM)
D5: CN1.2, IC1.2 (DQ), R1.1, RFU-1.18 (D5/PWM)
D6: Q1.2 (G), RFU-1.17 (D6/PWM)
D9: JP2.3, RFU-1.16 (D9/PWM)
D10: JP2.5, RFU-1.9 (D10/SS)
D12: JP2.7, RFU-1.6 (D12/MISO)
D13: JP2.9, RFU-1.8 (D13/SCK)
GND: -VE.1, BAT1.GND@1 (-), C1.2, C3.-, CN1.1, CN1.3, FTDI.6 (GND), IC1.1 (GND), IC1.3 (VDD), JP2.4, JP2.6, JP2.8, JP2.10, JP2.12, JP2.14, JP2.16, JP2.18, JP2.20, JP2.22, Q1.1 (S), RFU-1.10 (GND), U1.2 (GND), X1.1 (GND), X1.2 (GND)
unnamed: RFU-1.7 (D11/MOSI), RFU-1.20 (D2)
unnamed: MAXBOTIX-MB1.7, Q1.3 (D)
unnamed: +VE.1, U1.1 (VIN)
unnamed: C2.2, RFU-1.5 (!RESET)
unnamed: C2.1, FTDI.1 (DTR)
unnamed: FTDI.2 (RXI), RFU-1.2 (D1/TX)
unnamed: FTDI.3 (TXO), RFU-1.3 (D0/RX)
unnamed: ANT1.1, X1.3 (SIGNAL)

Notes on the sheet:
Released under a Creative Commons Attribution-ShareAlike 4.0 International License. http://creativecommons.org/licenses/by-sa/4.0/ Design by Andrew D. Lindsay, thinginnovations.com

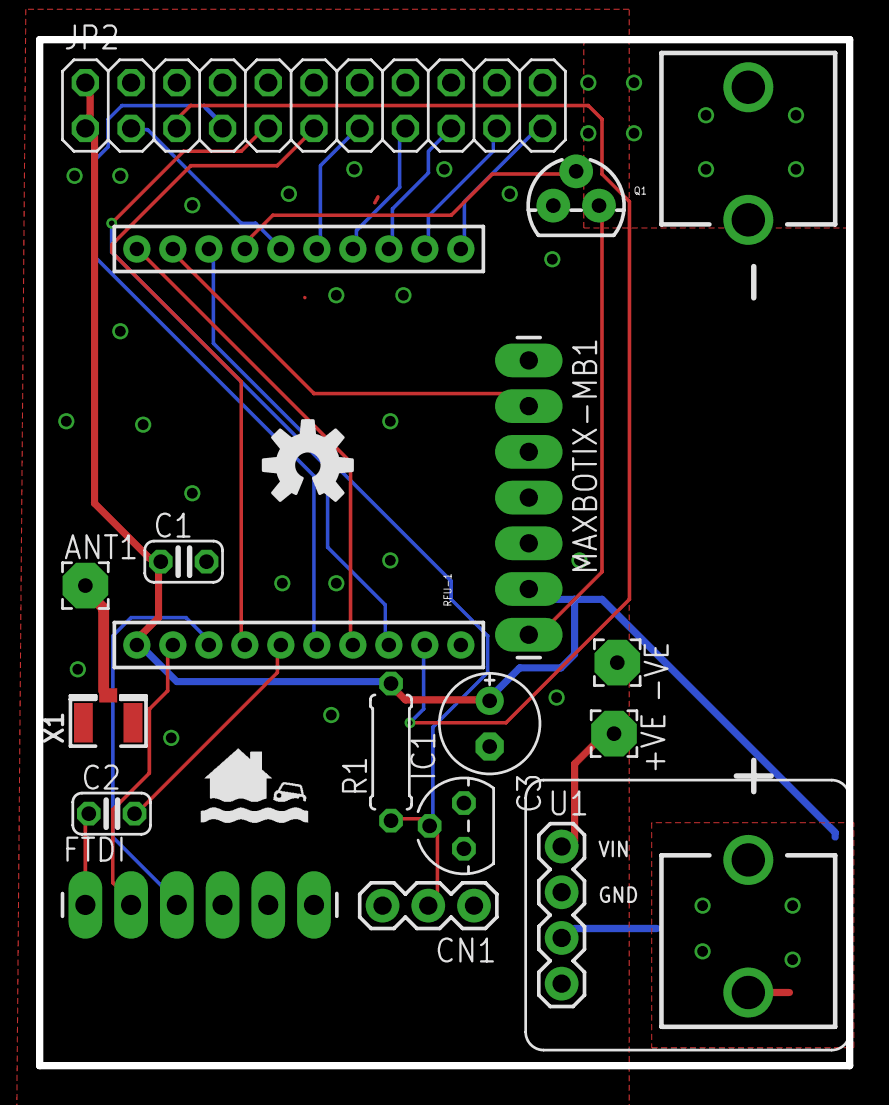
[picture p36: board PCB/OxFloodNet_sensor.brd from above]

Board: 2 copper layers, 45.0 x 57.1 mm, 18 parts (0 on the bottom side), 23 nets.

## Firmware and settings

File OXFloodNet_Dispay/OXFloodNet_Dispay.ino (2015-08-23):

/** OXFloodNet_Display, based on LLAPManager sketch for Ciseco RFu-328 and ST7735 based LCD
 * Using custom PCB with 5 way joystick for navigation
 * Extended for V4 sensors and LLAP Extended protocol.
 *
 * (c) Andrew D Lindsay, Thing Innovations 2015
 */

#define VERSION_STRING "V0.2"
#include <Adafruit_GFX.h>    // Core graphics library
#include <Adafruit_ST7735.h> // Hardware-specific library
#include <SPI.h>

#include "LLAPExtended.h"	// Extende LLAP library
#include "heart.h"        // Heartbeat logo
#include "logo.h"         // OxFloodNet Logo

// Application defines
// Display info
#define LCD_SIZE_X 160
#define LCD_SIZE_Y 128

// Re-define the colours as library is not correct for these displays
#define ST7735_BLACK   0x0000
#define ST7735_BLUE    0x001F
#define ST7735_RED     0xF800
#define ST7735_GREEN   0x07E0
#define ST7735_CYAN    0x07FF
#define ST7735_MAGENTA 0xF81F
#define ST7735_YELLOW  0xFFE0
#define ST7735_WHITE   0xFFFF

// text formatting options
#define TEXT_UNFORMAT 0
#define TEXT_CENTRED 1
#define TEXT_LEFT  2
#define TEXT_RIGHT 3

// joystick number
#define UP_KEY 0
#define DOWN_KEY 1
#define LEFT_KEY 2
#define RIGHT_KEY 3
#define CENTRE_KEY 4

#define JOYSTICK_NONE -1

// Joystick ports for portrait mode
//#define JOYSTICK_UP A0
//#define JOYSTICK_DOWN A1
//#define JOYSTICK_LEFT A2
//#define JOYSTICK_RIGHT A3
//#define JOYSTICK_CENTRE A4

// Joystick ports for Landscape mode, Joystick on Left
//#define JOYSTICK_UP A2
//#define JOYSTICK_DOWN A3
//#define JOYSTICK_LEFT A1
//#define JOYSTICK_RIGHT A0
//#define JOYSTICK_CENTRE A4

// Joystick ports for Landscape mode, Joystick on Right
#define JOYSTICK_UP A3
#define JOYSTICK_DOWN A2
#define JOYSTICK_LEFT A0
#define JOYSTICK_RIGHT A1
#define JOYSTICK_CENTRE A4

// SRF enable
#define SRF_RADIO_ENABLE 8

// LCD Display port definitions
#define TFT_CS   10
#define TFT_DC   9
#define TFT_RST  6  // you can also connect this to the Arduino reset

// SD Card enable pin
#define SD_CS 2

// Application specific defines
// Max number of nodes to store data for
#define MAX_NODES 10
// Times for indicating non responsive nodes. Assumes each transmits every 5 mins
//#define TESTING 1
#ifdef TESTING
#define TIME1 60000L
// 20 min
#define TIME2 1200000L
// 30 mins dead time
#define DEAD_TIME 120000L
#else
// 10 min
#define TIME1 600000L
// 20 min
#define TIME2 1200000L
// 30 mins dead time
#define DEAD_TIME 1800000L
#endif

// Display refresh to include non responsive nodes, 60s
//#define DISPLAY_REFRESH 60000L
#define DISPLAY_REFRESH 500L

// Battery reading below which colour changes for low battery
#define BATTERY_THRESHOLD 220

// Range test values
#define NO_RESP_TIME 5000

// Data Structures and global values
// Sensors - Keeps track of display position, last update time
// and battery voltage reading if available
typedef struct Sensors {
  byte x;        // X position on display
  byte y;        // Y position on display
  char msgType;  // a for original LLAP, b for Extended LLAP
  char id[8];    // Node ID
  char rdgType;  // Type of reading, for Extended LLAP
  char msg[16];  // Data plus \0 terminator
  int batt;      // Battery reading * 100, e.g. 250 = 2.50V
  long lastRx;   // Last receive time so can change colour and remove dead nodes
} Sensor;

int lastNodeNum = 0;
long lastUpdate = 0L;
boolean heartbeat = false;

// Node array of readings
Sensor node[MAX_NODES];

// Instantiate the Adafruit ST7735 library. Use SPI interface
Adafruit_ST7735 tft = Adafruit_ST7735(TFT_CS, TFT_DC, TFT_RST);

// Hardware specific functions
// ***************************
// Joystick
//keypad debounce parameter
#define DEBOUNCE_MAX 15
#define DEBOUNCE_ON  10
#define DEBOUNCE_OFF 3
#define NUM_KEYS 5

#define MENU_X	5		// 0-159
#define MENU_Y	30		// 0-127
#define TEXT_FONT_SIZE 2
#define TEXT_HEIGHT 18
//#define TEXT_FONT_SIZE 1
//#define TEXT_HEIGHT 12

byte joystickPorts[] = {
  JOYSTICK_UP, JOYSTICK_DOWN, JOYSTICK_LEFT, JOYSTICK_RIGHT, JOYSTICK_CENTRE
};
byte joystickKeys[] = {
  UP_KEY, DOWN_KEY, LEFT_KEY, RIGHT_KEY, CENTRE_KEY
};

// debounce counters
byte button_count[NUM_KEYS];
// button status - pressed/released
byte button_status[NUM_KEYS];
// button on flags for user program
byte button_flag[NUM_KEYS];

// Menu setup
#define NUM_MENU_ITEM 3
// Menu text
char menu_items[NUM_MENU_ITEM][15] = {
  "LLAP Display",
  "Range Test",
  "About"
};

// Functions for each menu option
void (*menu_funcs[NUM_MENU_ITEM])(void) = {
  llapDisplay,
  rangeTest,
  about
};

byte current_menu_item;

char *srfErrMsg[6] = { "Done",
                       "Cant set command mode",
                       "ATNT Failed",
                       "ATID Failed",
                       "ATDN Failed"
                     };

// Joystick functions

/** initJoystick - Set all the pint sof handing the joystick
 */
void initJoystick() {
  // Set joystick pint to input with internal pullup
  pinMode( JOYSTICK_UP, INPUT);
  digitalWrite( JOYSTICK_UP, HIGH);
  pinMode( JOYSTICK_DOWN, INPUT);
  digitalWrite( JOYSTICK_DOWN, HIGH);
  pinMode( JOYSTICK_LEFT, INPUT);
  digitalWrite( JOYSTICK_LEFT, HIGH);
  pinMode( JOYSTICK_RIGHT, INPUT);
  digitalWrite( JOYSTICK_RIGHT, HIGH);
  pinMode( JOYSTICK_CENTRE, INPUT);
  digitalWrite( JOYSTICK_CENTRE, HIGH);

  // setup interrupt-driven keypad arrays
  // reset button arrays
  for (byte i = 0; i < NUM_KEYS; i++) {
    button_count[i] = 0;
    button_status[i] = 0;
    button_flag[i] = 0;
  }

  // Setup timer2 -- Prescaler/256
  TCCR2A &= ~((1 << WGM21) | (1 << WGM20));
  TCCR2B &= ~(1 << WGM22);
  TCCR2B = (1 << CS22) | (1 << CS21);

  ASSR |= (0 << AS2);

  // Use normal mode
  TCCR2A = 0;
  //Timer2 Overflow Interrupt Enable
  TIMSK2 |= (0 << OCIE2A);
  TCNT2 = 0x6; // counting starts from 6;
  TIMSK2 = (1 << TOIE2);
  SREG |= 1 << SREG_I;
}


/** updateJoystickKey - ISR to debounce and update joystick positions
 */
void updateJoystickKey() {
  byte i;

  for (i = 0; i < NUM_KEYS; i++)
  {
    if ( digitalRead( joystickPorts[ i ] ) == LOW ) //one key is pressed
    {
      if (button_count[i] < DEBOUNCE_MAX)
      {
        button_count[i]++;
        if (button_count[i] > DEBOUNCE_ON)
        {
          if (button_status[i] == 0)
          {
            button_flag[i] = 1;
            button_status[i] = 1; //button debounced to 'pressed' status
          }
        }
      }
    }
    else // no button pressed
    {
      if (button_count[i] > 0)
      {
        button_flag[i] = 0;
        button_count[i]--;
        if (button_count[i] < DEBOUNCE_OFF) {
          button_status[i] = 0; //button debounced to 'released' status
        }
      }
    }
  }
}


/** getJoystick - Get the current joystick position
 * @return value to indicate which position joystick is in
 */
byte getJoystick() {
  for (int i = 0; i < NUM_KEYS; i++ ) {
    if ( button_flag[i] != 0 ) {
      button_flag[i] = 0; // reset button flag
      return joystickKeys[ i ];
    }
  }
  return JOYSTICK_NONE;
}


/** isJoystick - Quick test if the joystick is in a particular position
 * @return boolean true/false to indicate if joystick is in specified position
 */
boolean isJoystick( byte posn ) {
  return ( digitalRead( posn ) == LOW );
}


/** displayMenuUtem - Display a single menu option, highlight to show
 * it has been selected
 * @param menux - X position
 * @param menuy - Y position
 * @param text - Menu option character pointer, 0 terminated
 * @param highlight - boolean to indicate this is currently selected item
 */
void displayMenuItem(int menux, int menuy, char *text, boolean highlight ) {
  tft.setCursor(menux, menuy);
  tft.setTextSize(TEXT_FONT_SIZE);
  if ( highlight )
    tft.setTextColor(ST7735_BLACK, ST7735_CYAN);
  else
    tft.setTextColor(ST7735_CYAN, ST7735_BLACK);

  tft.setTextWrap(false);
  tft.print(text);
}


/** initMenu - Display all the menu items, highlight first item
 */
void initMenu() {
  for ( int i = 0; i < NUM_MENU_ITEM; i++ ) {
    displayMenuItem(MENU_X, MENU_Y + (i * TEXT_HEIGHT), menu_items[i], (i == 0 ? true : false) );
  }
  current_menu_item = 0;
  showNodeCount();
}


/** toggleHeartbeat - Display the heart and alternate its colour form red to black
 * to make it flash on and off.
 */
void toggleHeartbeat( ) {
  tft.drawBitmap(122, 15, heart, 32, 32, heartbeat ?  ST7735_RED : ST7735_BLACK );
  heartbeat = heartbeat ? false : true;
}


/** displayRSSI - display the current RSSI value
 * @param rssi - pointer to character string representation of RSSI from message
 */
void displayRSSI( char *rssi ) {
  tft.setTextColor(ST7735_YELLOW, ST7735_BLACK);
  tft.setCursor(2, 50);
  tft.setTextSize(9);
  tft.print(rssi);
  tft.print("   ");
}

void displayError( uint16_t fCol, uint16_t bCol, char* errMsg ) {
  tft.setTextColor(fCol, bCol);
  tft.println(errMsg);
}

/** rangeTest - The range test menu option. Requires the slave
 * module to be used with this.
 */
void rangeTest() {
  setScreen( (char*)"Range Test" );

  digitalWrite(SRF_RADIO_ENABLE, LOW); // select the radio
  tft.setTextColor(ST7735_GREEN, ST7735_BLACK);
  tft.setTextSize(1);
  tft.setCursor(1, 30);
  tft.println("Setting up SRF");

  // Need to set RSSI Master mode
  uint8_t ret = setupSRF();
  tft.setTextSize(1);
  tft.setCursor(1, 30);
  if ( ret > 0 ) {
    displayError(ST7735_RED, ST7735_BLACK, srfErrMsg[ret]);
    delay(10000);
  } else
    tft.println(srfErrMsg[ret]);
  /*
    switch ( ret ) {
      case 1:
        displayError(ST7735_RED, ST7735_BLACK, "Cant set command mode");
        break;
      case 2:
        displayError(ST7735_RED, ST7735_BLACK, "ATNT Failed");
        break;
      case 3:
        displayError(ST7735_RED, ST7735_BLACK, "ATID Failed");
        break;
      case 4:
        displayError(ST7735_RED, ST7735_BLACK, "ATDN Failed");
        break;
      case 5:
        tft.println("Done");
        break;
    }
  */
  digitalWrite(SRF_RADIO_ENABLE, HIGH); // select the radio

  if ( ret > 0 ) {
//    delay(10000);
    return;
  }

  lastUpdate = millis();

  tft.setTextColor(ST7735_GREEN, ST7735_BLACK);
  tft.setTextSize(2);
  tft.setCursor(1, 22);
  tft.println("RSSI Value");

  displayRSSI( "000" );

  // Initialise the LLAPSerial library
  LLAP.init();

  while ( !isJoystick( JOYSTICK_CENTRE ) ) {
    // Wait for message
    if (LLAP.bMsgReceived) {
      char msgArray[15];
      LLAP.sMessage.toCharArray(msgArray, 12 );
      msgArray[12] = '\0';
      char valArray[10];

      if ( LLAP.sMessage.substring(0, 5).equalsIgnoreCase( "RSSIS") ) {
        toggleHeartbeat();
        //String barCountStr = LLAP.sMessage.substring(4,5);
        LLAP.sMessage.substring(6 ).toCharArray( valArray, 4);
        displayRSSI( valArray );

      }

      lastUpdate = millis();
      LLAP.bMsgReceived = false;	// if we do not clear the message flag then message processing will be blocked
    }
    if ( lastUpdate + NO_RESP_TIME < millis() ) {
      // No response
      tft.drawBitmap(122, 15, heart, 32, 32, ST7735_BLUE );
    }

    long nowTime = millis();
    while ( nowTime + 500 < millis()) {
      receiveLLAP();
      LLAP.bMsgReceived = false;	// if we do not clear the message flag then message processing will be blocked
      nowTime = millis();
    }
    LLAP.SerialEvent();
  }

  tft.setTextSize(1);
  tft.setCursor(1, 30);
  tft.setTextColor(ST7735_GREEN, ST7735_BLACK);
  tft.println("Restoring SRF");

  ret = restoreSRF();

  tft.setTextSize(1);
  tft.setCursor(1, 30);
  if ( ret > 0 ) {
    displayError(ST7735_RED, ST7735_BLACK, srfErrMsg[ret]);
    delay(10000);
  } else
    tft.println(srfErrMsg[ret]);
  /*
    switch ( ret ) {
      case 1:
        displayError(ST7735_RED, ST7735_BLACK, "Cant set command mode");
  //      delay(10000);
        break;
      case 2:
        displayError(ST7735_RED, ST7735_BLACK, "ATNT Failed");
  //      delay(10000);
        break;
      case 3:
        displayError(ST7735_RED, ST7735_BLACK, "ATID Failed");
  //      delay(10000);
        break;
      case 4:
        displayError(ST7735_RED, ST7735_BLACK, "ATDN Failed");
  //      delay(10000);
        break;
      case 5:
        tft.println("Done");
        break;
    }
  */
  //  if ( ret < 5 )
  //    delay(10000);

  digitalWrite(SRF_RADIO_ENABLE, HIGH); // select the radio

  LLAP.init();

}


/** llapDisplay - Main display for received LLAP messages
 * Handles aging of reading so that non functioning nodes will
 * be automatically removed. Only 10 readings are stored.
 * Pressing joystick centre button will exit and return to menu.
 */
void llapDisplay() {
  setScreen( (char*)"LLAP Display" );
  int blankLines = 0;
  lastUpdate = millis();
  while ( !isJoystick( JOYSTICK_CENTRE ) ) {
    if (LLAP.bMsgReceived) {
      displayNode( setNode(LLAP.cMessage) );
      LLAP.bMsgReceived = false;	// if we do not clear the message flag then message processing will be blocked
    }
    // Display refresh every minute to show nodes that have dropped out
    long now = millis();
    if ( (lastUpdate + DISPLAY_REFRESH) < now ) {
      int blankLines = deadNodeCheck();
      refreshDisplay( blankLines );
      lastUpdate = millis();
      if ( isJoystick( JOYSTICK_CENTRE ) )
        return;
    }
    LLAP.SerialEvent();
  }
}


/** formatText - format and display text
 * @param x - X position of text
 * @param y - Y position of text
 * @param textSize - Size of text to display. 1-4 with 4 being largest
 * @param format - Lef, right or centred text
 * @param text - pointer to 0 terminated character string to display.
 */
void formatText( int x, int y, int textSize, int format, char *text ) {
  // format text on display
  tft.setTextSize( textSize);
  int pixelsChar = 6;
  switch ( textSize ) {
    case 1:
      pixelsChar = 6;
      break;
    case 2:
      pixelsChar = 12;
      break;
    case 3:
      pixelsChar = 15;
      break;
    case 4:
      pixelsChar = 18;
      break;
  }

  switch ( format ) {
    case TEXT_CENTRED:    // Centered
      x = (LCD_SIZE_X / 2 - ((strlen(text) * pixelsChar) / 2));
      break;
    case TEXT_LEFT:      // Left justified
      x = 0;
      break;
    case TEXT_RIGHT:     // Right Justified
      x = LCD_SIZE_X - (strlen(text) * pixelsChar);
      break;
    default:             // None
      break;
  }

  tft.setCursor(x, y);
  tft.println( text );
}


/** about - Display the about screen and wait for joystick centre
 *  button to be pressed before returning to the menu.
 */
void about() {
  setScreen( (char*)"About" );
  tft.setTextColor(ST7735_GREEN, ST7735_BLACK);

  formatText(0, 20, 2, TEXT_CENTRED, "Oxford Flood" );
  formatText(0, 40, 2, TEXT_CENTRED, "Network" );
  formatText(0, 60, 2, TEXT_CENTRED, "LLAP Display" );
  formatText(0, 80, 2, TEXT_CENTRED, VERSION_STRING );
  formatText(0, 100, 1, TEXT_CENTRED, "By Andrew Lindsay" );
  formatText(0, 110, 1, TEXT_CENTRED, "@ThingInnovation" );
  formatText(0, 120, 1, TEXT_CENTRED, "For @oxfloodnet" );

  // Displayed until joystick centre button pressed
  while ( !isJoystick( JOYSTICK_CENTRE ) ) {
    receiveLLAP();
    LLAP.bMsgReceived = false;	// if we do not clear the message flag then message processing will be blocked
    LLAP.SerialEvent();
  }
}


/** initNodes - Initialise our node data
 * Set default values for each node element
 */
void initNodes() {
  for (int i = 0; i < MAX_NODES; i++) {
    node[i].x = -1;
    node[i].y = -1;
    node[i].msgType = '-';
    for (int j = 0; j < 8; j++ )
      node[i].id[j] = '-';
    node[i].rdgType = '-';
    node[i].msg[0] = '\0';
    node[i].batt = -1;
    node[i].lastRx = 0L;
  }
  lastNodeNum = 0;
}


/** getNodeId -  Given a node id, locate a node record or -1 if not present
 * Use reading type if using LLAPExtended format
 * @param msgType - The message type, a or b
 * @param id - Pointer to array containing the id
 * @param rdgType - Reading type, used in b only as multiple readings are sent by the sensors
 * @return index for the node or -1 if not found.
 */
int getNodeId( char msgType, char *id, char rdgType ) {
  if ( msgType == 'a' ) {
    for ( int i = 0; i < lastNodeNum; i++ ) {
      if ( id[0] == node[i].id[0] && id[1] == node[i].id[1] )
        return i;
    }
  } else if ( msgType == 'b' ) {
    // Check message type as sensors can send 3 messages
    for ( int i = 0; i < lastNodeNum; i++ ) {
      // TODO: Try strncmp
      if ( id[0] == node[i].id[0] && id[1] == node[i].id[1] &&
           id[2] == node[i].id[2] && id[3] == node[i].id[3] &&
           id[4] == node[i].id[4] && id[5] == node[i].id[5] &&
           id[6] == node[i].id[6] && id[7] == node[i].id[7] &&
           rdgType == node[i].rdgType )
        return i;
    }
  }

  return -1;
}


/** setNode - update stored node data from new receive message
 * Msg is aNNddddddddd (12) or bNNNNNNNNddddddddd (18)
 * Filter out awake and sleep messages.
 * For BATT, only update the battery voltage except for type b as this is a separate message
 * @param msg - pointer to received message
 * @return
 */
int setNode( char *msg ) {
  char id[8] = { '-', '-', '-', '-', '-', '-', '-', '-' };
  char msgType = *msg++;
  char rdgType = '-';

  // msgType a - 2 char id, b - 8 char id
  if ( msgType == 'a' ) {
    id[0] = *msg++;
    id[1] = *msg++;
  } else if ( msgType == 'b' ) {
    for ( int i = 0; i < 8; i++ )
      id[i] = *msg++;
  }

  // Ignore START, SLEEPPING and WAKE messages
  if ( strncmp(msg, "START", 5 ) == 0 ||
       strncmp(msg, "SLEEP", 5 ) == 0 ||
       strncmp(msg, "AWAKE", 5 ) == 0)
    return -1;    // No update

  if ( msgType == 'b' ) {
    rdgType = *msg;
  } else rdgType = '-';

  int nodeNum = getNodeId( msgType, id, rdgType );
  if ( nodeNum == -1 ) {
    if ( (lastNodeNum + 1) >= MAX_NODES )
      return -1;

    nodeNum = lastNodeNum++;

    // Set unchanging values, position and node
    node[nodeNum].x = 2;
    node[nodeNum].y = 15 + (nodeNum * 10);
    node[nodeNum].msgType = msgType;

    // Set Node ID
    if ( msgType == 'a' ) {
      node[nodeNum].id[0] = id[0];
      node[nodeNum].id[1] = id[1];
    } else if ( msgType == 'b' ) {
      for ( int i = 0; i < 8; i++ )
        node[nodeNum].id[i] = id[i];

      node[nodeNum].rdgType = rdgType;
      msg++;    // Skip rdgType
    }

    //    strncpy(node[nodeNum].msg, "---------", 9);
    //    node[nodeNum].msg[9] = '\0';
    node[nodeNum].batt = -1;
    showNodeCount();
  }

  node[nodeNum].lastRx = millis();

  // Set Battery voltage if BATT received
  if ( msgType == 'a' ) {
    if ( strncmp(msg, "BATT", 4 ) == 0 ) {
      node[nodeNum].batt = (int)(atof( &msg[4] ) * 100);
      return -1;
    }
    else {
      // TODO: Strip trailing -
      strncpy( node[nodeNum].msg, msg, 9);
    }
  } else if ( msgType == 'b' ) {
    // Strip trailing -
    //msg++;
    strncpy( node[nodeNum].msg, msg, 9);
    if ( node[nodeNum].msg[8] == '-' ) {
      int count = 8;
      while ( node[nodeNum].msg[count] == '-' && count > 0 ) {
        node[nodeNum].msg[count--] = '\0';
      }
    }

  } else {
    // TODO: Strip trailing -
    strncpy( node[nodeNum].msg, msg, 9);
    if ( node[nodeNum].msg[8] == '-' ) {
      int count = 8;
      while ( node[nodeNum].msg[count] == '-' && count > 0 ) {
        node[nodeNum].msg[count--] = '\0';
      }
    }
  }

  return nodeNum;
}
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
void loop() {

  byte i;
  for (i = 0; i < NUM_KEYS; i++) {
    if (button_flag[i] != 0) {

      button_flag[i] = 0; // reset button flag
      switch (i) {
        case UP_KEY:
          // current item to normal display
          displayMenuItem(MENU_X, MENU_Y + (current_menu_item * TEXT_HEIGHT), menu_items[current_menu_item], false );
          current_menu_item -= 1;
          if (current_menu_item < 0)  current_menu_item = NUM_MENU_ITEM - 1;
          // next item to highlight display
          displayMenuItem(MENU_X, MENU_Y + (current_menu_item * TEXT_HEIGHT), menu_items[current_menu_item], true );
          break;
        case DOWN_KEY:
          // current item to normal display
          displayMenuItem(MENU_X, MENU_Y + (current_menu_item * TEXT_HEIGHT), menu_items[current_menu_item], false );
          current_menu_item += 1;
          if (current_menu_item > (NUM_MENU_ITEM - 1))  current_menu_item = 0;
          // next item to highlight display
          displayMenuItem(MENU_X, MENU_Y + (current_menu_item * TEXT_HEIGHT), menu_items[current_menu_item], true );
          break;
        case LEFT_KEY:
          initMenu();
          current_menu_item = 0;
          break;
        case RIGHT_KEY:
          (*menu_funcs[current_menu_item])();
          setScreen( (char*)"OxFloodNet" );
          initMenu();
          current_menu_item = 0;
          break;
      }
    }
  }
  receiveLLAP();
  LLAP.bMsgReceived = false;	// if we do not clear the message flag then message processing will be blocked
}


// Timer2 interrupt routine -
// 1/(160000000/256/(256-6)) = 4ms interval

ISR(TIMER2_OVF_vect) {
  TCNT2  = 6;
  updateJoystickKey();
}
// That's all folks

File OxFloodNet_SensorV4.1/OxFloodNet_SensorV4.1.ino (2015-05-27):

/** 
 * OxFloodNet_Sensor sketch for Ciseco RFu-328 and Maxbotix MB7060 XL-MaxSonar-WR1, Standard edition ultrasonic sensor
 *
 * Transmits reading every 1, 5, 10 or 15 minutes depending on jumpers. Default is 15 minutes
 *
 * Data Format:
 * Data transmitted is of form        bXXXXXXXXUnnn-----
 * Battery readings every 10th cycle  bXXXXXXXXBvvvv----
 *
 * Where XX is the device ID, nnn is the distance to the water in cm, vvvv is battery voltage in mV
 * Other messages sent are: aXXXXXXXXSTARTvvv- upon startup, vvv is version ID
 * aXXXXXXXXUMax----- and aXXXXXXXXUErr----- if max range is reached or an error in the reading is seen, i.e. too close.
 * aXXXXXXXXUnnnn----, aXXXXXXXXDnnnn---- and aXXXXXXXXTnn.n----
 * D is compensated distance, U is Raw Distance, T is temperature and B is battery reading
 *
 * Original LLAP Format:
 * Data transmitted is of form aXXUnnn-----
 * Battery readings every 10th cycle  aXXBvvvv----
 *
 * Where XX is the device ID, nnn is the distance to the water in cm, vvvv is battery voltage in mV
 * Other messages sent are: aXXSTARTvvv- upon startup, vvv is version ID
 * aXXUMax----- and aXXUErr----- if max range is reached or an error in the reading is seen, i.e. too close.
 * aXXUnnnn----, aXXDnnnn---- and aXXTnn.n----
 * D is compensated distance, U is Raw Distance, T is temperature and B is battery reading
 *
 * Hardware:
 * Sensor is controled using a single N-Channel MOSFET, Gate to SENSOR_ENABLE,
 * Source to GND, Drain to -ve of sensor, Sensor +ve to +3V.
 *
 * For first 10 minutes after reset/powerup, sensor wakeup is every twenty seconds (
 * for next 10 minutes the sleep is every 1 minutes, after this sleep interval
 * becomes value set on jumpers (5, 10 or 15 mins) 
 *
 * Jumpers: 1  2
 * 15 mins  -  -
 * 10 mins  X  X
 *  5 mins  -  X
 *  1 min   X  -
 * (c) 2015 Andrew D Lindsay & Ben Ward for Oxford Flood Network http://oxfloodnet.co.uk/  @oxfloodnet 
 *
 */

#include "LLAPExtended.h"
#include <OneWire.h>
#include <DallasTemperature.h>

// Used in START msg to indicate firmware version, 412 = 4.1.2
#define VERSION_ID 411

// Set RFu hardware pins (not board jumpers)
// Enable SRF
#define SRF_RADIO_ENABLE 8
// Enable the sensor, controlled by FET
#define SENSOR_ENABLE 6
// Pin that sensor PWM input is on
#define SENSOR_PIN 3
// Using Sleep Mode 3, SLEEP must be LOW to run, uses interrupt to wakeup
#define SRF_SLEEP 4
#define WAKE_INT 2

// Test pin - if jumpered then enter test mode.
#define TEST_MODE 13

// Temperature sensor data line connects to pin 5 on the Arduino
// OneWire bus pin for temperature sensor pin
#define ONE_WIRE_BUS 5

// Software configuration defines
// Number of readings before a battery reading is taken
#define BATTERY_READ_INTERVAL 10

// Polling interval jumper link enumeration values, 1, 5, 10 or 15 minutes
#define FIFTEENMINS 0
#define TENMINS 1
#define FIVEMINS 2
#define ONEMIN 3
#define TWENTYSEC 4

// Define AT commands for setting up normal operation
#define NUM_SRF_CMDS 6
char *srfConfigCmds[] = {
  "ATID5AA5",    // PANID default
  "ATPK0C",      // Packet size, 12
  "ATDR1",       // Data Rate ????kb/s
  "ATSM3",       // Sleep Mode 3
  "ATAC",        // Use config
  "ATDN"         // Exit AT mode
};

// Define AT commands to set polling intervals defined above
// Order is Fifteen Mins, Ten Mins, Five Mins, 1 Min, 20 seconds
char *pollingIntervalCmds[] = { 
  "ATSDDBBA0",  // 15 Minutes
  "ATSD927C0",  // 10 Minutes
  "ATSD493E0",  // 5 Minutes
  "ATSDEA60",   // 1 Minute
  "ATSD4E20"    // 20s
};

// define startup polling modes
// 10 minutes of 20s interval is 30 wakeups
// After 10 mins this is reset to 10 and interval is 1 minute 
#define NORMAL_POLL 0
#define MED_POLL 1
#define FAST_POLL 2

// Counts for the startup polling modes
#define FAST_POLL_COUNT 30
#define MED_POLL_COUNT 10

// Hardware objects

// Setup a oneWire instance to communicate with any OneWire devices (not just Maxim/Dallas temperature ICs)
OneWire oneWire(ONE_WIRE_BUS);

// Pass our oneWire reference to Dallas Temperature library.
DallasTemperature sensors(&oneWire);

// arrays to hold device address
DeviceAddress temperatureSensor;

// Define pins that are not used and are to be made inputs for power saving
// TODO: Check usage of all pins
#define PIN_COUNT 11

uint8_t inPin[] = { 
  9, 10, 11, 12, 13, A0, A1, A2, A3, A4, A5 };

// Other global variables
boolean tempSensorFound = false;
uint8_t batteryCountDown = BATTERY_READ_INTERVAL;
uint8_t pollingInterval = FIFTEENMINS;
uint8_t startupSequence = FAST_POLL;
uint8_t startupCounter = FAST_POLL_COUNT;
uint16_t fwVersion = VERSION_ID;

// Node ID, default 00000000, value is read from DS18B20 temperature sensor unique ID
char nodeId[8] = { 
  '0','0','0','0','0','0','0','0' };

// External functions
extern void testMode();

/** readJumpers - determine node ID and polling interval for this sensor
 */
void readJumpers() {
  // Set pins input pins to read digital values, set internal pullup
  uint8_t jumperPins[] = { 9, 10  };
  for( int n = 0; n < 2; n++ ) {
    pinMode( jumperPins[n], INPUT );
    digitalWrite( jumperPins[n], HIGH);
  }

  // Set polling interval from jumper pins
  uint8_t pin1 = digitalRead( 10 );
  uint8_t pin2 = digitalRead( 9 );
  pollingInterval = (pin2 << 1 | pin1) ^ 0x03;

  // Reset inputs to set internal pullup off
  for( uint8_t n = 0; n < 2; n++ ) {
    digitalWrite( jumperPins[n], LOW);
  }
}

// Functions used in processing readings

/* isort - Simple sort function for the set of readings
 * Sorting function (Author: Bill Gentles, Nov. 12, 2010)
 * The sorted array is returned in the original array
 * @param a - Array of unsigned 16 bit values to sort
 * @param n - Number of values in array
 */
void isort(uint16_t *a, int8_t n){
  for (int i = 1; i < n; ++i)  {
    uint16_t j = a[i];
    int k;
    for (k = i - 1; (k >= 0) && (j < a[k]); k--) {
      a[k + 1] = a[k];
    }
    a[k + 1] = j;
  }
}


/** mode - Mode function, returning the mode or median.
 * @param x - Array of unsigned 16 bit values to sort
 * @param n - Number of values in array
 * @return mode or median of the passed data.
 */
uint16_t mode(uint16_t *x,int n){
  uint8_t i = 0;
  int count = 0;
  int maxCount = 0;
  uint16_t mode = 0;
  int bimodal;
  int prevCount = 0;
  while(i<(n-1)){
    prevCount=count;
    count=0;
    while( x[i]==x[i+1] ) {
      count++;
      i++;
    }
    if( count > prevCount & count > maxCount) {
      mode=x[i];
      maxCount=count;
      bimodal=0;
    }
    if( count == 0 ) {
      i++;
    }
    if( count == maxCount ) {      //If the dataset has 2 or more modes.
      bimodal=1;
    }
    if( mode==0 || bimodal==1 ) {  // Return the median if there is no mode.
      mode=x[(n/2)];
    }
    return mode;
  }
}

// Start of Ultrasonic sensor code
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

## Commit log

2014-03-23 Added images of custom PCB
    Andrew Lindsay's custom PCB photos
2014-03-23 Created readme with details of schematic & code
2014-03-23 Added note about schematic bug
2014-03-30 Uploaded schematic
2014-03-30 First commit of sensor firmware
2014-07-14 add eagle files
    [OxFloodNet_Sensor_BOM.xlsx, OxFloodNet_sensor.brd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]
2014-07-26 Image of PCB
    Created Image file from EAGLE
2014-07-26 Major readme update
    Includes version number, board features, options, link to assembly guide.
2014-07-26 Sensor models added
2014-07-27 Updated to v3.1
    [OxFloodNet_sensor.brd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]
2014-08-11 Sensor BOM minor change
    [OxFloodNet_Sensor_BOM.xlsx]
2014-08-17 Updated for V3.1 PCB
2014-09-11 Clarification on sensor ID
2014-09-11 Made Battery reading not mutually exclusive
    Distance reading now happens after battery reading, where before it was
    not performed when a battery reading was done.
2014-09-28 Revert "v3.1.3 tidy up & version number broadcast"
    This reverts commit 93fb807c3dc9b83a4bc0ffd53110faf6d76fad14.
    [OxFloodNet_Sensor.ino]
2014-11-07 Made battery reading not mutually exclusive
    Previously battery reading was performed instead of distance reading
    every nth cycle. It's now sent at the same time to ensure no gaps in the
    flood data.
2015-02-12 Version 3.1.5 - Fixes for temperature compensation
    New version fixes temperature compensation bug.
    [OxFloodNet_Sensor.ino]
2015-05-21 Added V4.1 sensor PCB and code
    [OxFloodNet_sensor.brd, OxFloodNet_sensor.sch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]
2015-05-22 Added sample NR flow
2015-05-27 Corrected node ID conversion
    [OxFloodNet_SensorV4.1.ino]
2015-06-09 Checkin BOM
    BOM
    [OxFloodNet_Sensor_BOM.xlsx]
2015-06-10 Added long pins header
    [OxFloodNet_Sensor_BOM.xlsx]
2015-06-10 additonal notes
    [OxFloodNet_Sensor_BOM.xlsx]
2015-08-17 LCD Display
    Added LCD Display sketch for using as a test device.
2015-08-23 Refactoring
    Refactoring parts of code to reduce both Flash and RAM footprint and
    get rid of duplicate code.

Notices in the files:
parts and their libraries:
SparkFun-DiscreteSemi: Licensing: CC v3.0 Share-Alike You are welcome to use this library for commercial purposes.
